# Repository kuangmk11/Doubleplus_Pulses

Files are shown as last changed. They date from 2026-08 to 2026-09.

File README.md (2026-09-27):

# Pulses Plus

A performance-oriented gate router for the Music Thing Turing Machine. Eight pulse channels,
each switchable to one of two merge buses or off; each bus computes the OR or the AND of
whatever is routed to it, chosen live from the panel.

<p align="center">
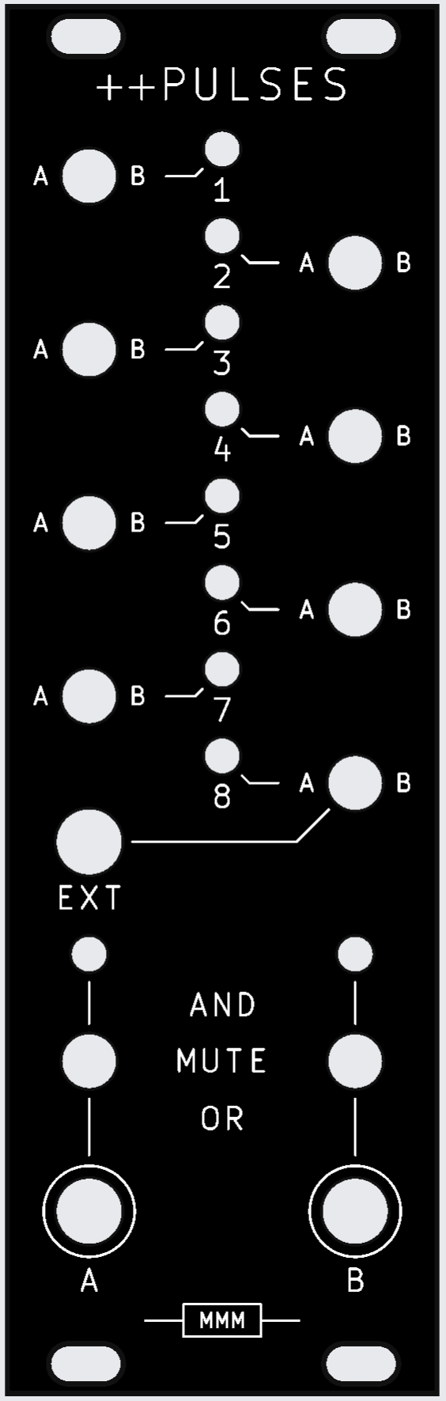
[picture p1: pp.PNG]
Pulses Plus front panel, v4
  
</p>

**Built and tested.** 8 HP, 128.5 × 40.16 mm.

It sits **alongside** a stock Pulses expander rather than replacing it, taking its signals from
the Turing Machine's 16-pin expander ribbon and passing that ribbon through so other expanders
can still be chained downstream.

The stock Pulses gives you seven fixed outputs plus four hard-wired AND combinations. Those AND
outputs are the musical ones — ANDing two shift-register taps gives a sparser, related rhythm.
This generalises that: any subset of the eight bits, OR'd or AND'd, chosen by hand, live. The
four fixed ANDs become a strict subset of what the switches can do.

---

## What's here

| | |
|---|---|
| `pulses_plus_submin.kicad_sch` | schematic — 87 placed components |
| `pulses_plus_submin.kicad_pcb` | main board |
| **`pulses_plus_submin_panel_v4.kicad_pcb`** | **current panel** |
| `pulses_plus_submin_panel.kicad_pcb` | v1 panel — the geometry source `build_panel.py` inherits holes from |
| `pulses_plus_submin.pretty/` | project footprints — toggle, jack, LED, panel holes |
| `switch_fix.kicad_sym` | the DPDT symbol with the pin numbering the footprint expects |
| `3d/` | 3D models the footprints reference |
| `BOM.md` | bill of materials, DigiKey and JLCPCB/LCSC columns |
| `BOM_DigiKey.csv` | the same BOM as a DigiKey cart upload |
| `gerbers/` | fab packages — see below |
| `tools/build_panel.py` | regenerates the panel artwork |
| `PANEL_STYLE_v1.12.md` | the panel house style |
| `docs/pulses-plus-design.md` | full design write-up, including the diode-leak analysis and why 6 HP was abandoned |
| `docs/sw-t2-4x-b-a2-ma2-data-sheet.pdf` | Taiway 200-MDP3 toggle datasheet |

### Which gerbers to order

`gerbers/` accumulated every revision that was sent out. The panel to order is
`gerbers/panelv4.rar`. For the board:

- **`gerbers_v2/`** — current plot of `pulses_plus_submin_v2.kicad_pcb`, **including C5/C6**
  (see the erratum below). Not yet fabbed.
- **`gerbers/controlv2.zip`** — what was actually fabbed and built. Boards from this package
  predate C5/C6 and need the two-capacitor rework.

The loose `.gbr`/`.drl` files at the top of `gerbers/` are the most recent plot of the
main board and the v1/v2 panels, kept unzipped for inspection.

---

## Erratum — ghost triggers on edge-sensitive gate inputs

**Any board built without C5/C6 needs a two-capacitor rework.**

**Symptom.** On the step *after* a real trigger — a step where the bus should be silent — a
downstream envelope fires an extra time. The bus LED never visibly flashes, and the same envelope
behaves correctly on the Turing Machine's own pulse output and on a stock Pulses. A **Kassutronics
ASR** is the known case; the affected class is any gate input that triggers on the *rising edge* at
a low threshold (the ASR's fires from ~+1.2 V).

**Cause.** The Turing Machine's expander bits are `stage AND clock`, and the clock's rising edge
opens that AND before the shift register has finished shifting — so the ribbon briefly presents the
previous step's pattern. This module's two cascaded CD40106 Schmitt buffers then regenerate that
soft sub-µs bump into a sharp, near-full-amplitude micro-gate. Full analysis in
[`docs/pulses-plus-design.md`](docs/pulses-plus-design.md#stale-bit-glitch-and-edge-sensitive-gate-inputs).

**Fix.** Tack a **4.7 nF** ceramic on top of **R15**, and another on top of **R16**. Those 1206 pads
are already `BUSA_SEL`→GND and `BUSB_SEL`→GND on the back of the board, so there are no trace cuts,
no lifted pins, and it is fully reversible. Verified on hardware.

- **Do not use a smaller value.** 1 nF was measured insufficient; 2.2 nF computes marginal.
- **Multing the output is not a workaround.** It appears to help and then stops helping — cable
  capacitance is an order of magnitude too small to filter this.
- The fix is in the **v2** project files (`pulses_plus_submin_v2.*`) as C5/C6. The v1 files do not
  have it.

## How it works

Each channel's DPDT ON-OFF-ON toggle throws left to bus A, right to bus B, or centre for off.
Both poles are used: pole 1 carries only the OR diodes, pole 2 only the AND diodes. That
separation is the one non-obvious constraint in the design — sharing a pole leaks current
through the unselected bus and pins its OR net high.

Per bus, a second toggle picks OR, MUTE or AND. Both nets are computed continuously and in
parallel, so the mode switch only selects which one reaches the output buffer and the 32 merge
diodes never switch. Centre-off leaves the buffer input pulled low, which is the mute.

The **EXT** jack is switched (normalled): unplugged, buffered BIT8 feeds channel 8; plugged, an
external gate takes its place through a transistor and Schmitt stage that squares up whatever
amplitude arrives.

Full write-up: **[`docs/pulses-plus-design.md`](docs/pulses-plus-design.md)**.

## Using it

The two buses are **two independent reads of the same shift register**. Whatever either one
plays is built from the same eight bits on the same loop, so they cannot drift apart — but give
them different channels, or put one in AND and the other in OR, and they come out at different
densities. Related, never identical. Most of the musical mileage is in that gap.

### Gates on A, note changes on B

The patch this turned out to be best at, and not one it was designed for:

1. **OUT A → your envelope or VCA gate.** A few channels to bus A in **OR** — a busy,
   rhythmic gate stream.
2. **OUT B → a quantizer's trigger or sample input**, with the Turing Machine's CV output
   feeding that quantizer's CV input. A *different*, smaller set of channels to bus B, in
   **AND** for something sparser again.

The quantizer only samples when bus B fires, so the note is **held** across every gate bus A
produces in between. A melody moves on its own slow rhythm while the gates articulate
underneath — and because both rhythms are subsets of one register, the note changes land on
beats the gate pattern already stresses. It reads as a phrase, not as two voices running at
once.

Being a Turing Machine underneath, the loop-length and randomness controls then act on the
whole thing at once: lock the register for a repeating riff, open it a crack and the melody
mutates while staying in its scale.

**Pulse width passes straight through.** The board is purely combinational: it merges what
arrives on the ribbon and never looks at the clock. It does not need to — the Turing Machine's
expander bus already carries each bit ANDed with the clock, so the bits arrive as *pulses*, and
the diode merge preserves their width. Feed the TM a narrow clock and the outputs are narrow;
feed it a wide one and they are wide, all the way to OUT A and OUT B.

So an AND that is true on three consecutive steps gives three pulses, one per step — each
re-triggering the envelope or re-pinging the quantizer, rather than merging into one long gate.
The note changes on every step the condition holds, which is why choosing a condition that comes
true *rarely* is what makes the melody move slowly.

**Things to reach for:**

- **B in AND with two or three channels** is the sweet spot. AND of several bits comes true
  rarely, which is what you want from a melody that moves every few bars rather than every step.
- **MUTE on B** freezes the pitch without touching the gate pattern — drop the melody in and
  out by hand mid-take. That is what the centre position is for.
- **The EXT jack earns its keep here.** Patch an outside rhythm into channel 8 and AND it into
  bus B, and the note only changes where your own pattern and the Turing Machine agree —
  a melody keyed to something the TM knows nothing about.
- An **AND bus with nothing routed to it sits high**, held there by its 10k pull-up rather than
  driven by any bit, so it never pings anything. Route at least one channel to a bus you want
  triggers from.

## Key parts

10 × Taiway 200-MDP3 sub-miniature DPDT ON-OFF-ON toggles (ø4.95 bushing), 2 × CD4050 buffers,
1 × CD40106 Schmitt, 33 × 1N4148, 10 × 3 mm LEDs, 3 × Thonkiconn jacks — **J3 must be the
switched variant** — and 2 × 2×8 IDC headers for ribbon in and thru. See [`BOM.md`](BOM.md).

---

## Panel

The current panel is **v4**, `pulses_plus_submin_panel_v4.kicad_pcb` — white silkscreen on black
soldermask, drawn to [`PANEL_STYLE_v1.12.md`](PANEL_STYLE_v1.12.md).

It is generated. [`tools/build_panel.py`](tools/build_panel.py) reads the v1 panel and regenerates
only the artwork, inheriting every control-hole position, so the style guide's one non-negotiable
rule — hole positions are inherited, never computed — holds by construction rather than by
inspection:

```sh
python3 tools/build_panel.py
```

Mounting is four 6.4 × 3.2 mm obround slots on Edge.Cuts, horizontal for ±1.6 mm of slide.
`kicad-cli pcb drc` reports zero violations. Zones refill on open — refill before plotting.

Reading the panel: a ring means signal leaves there, so the two output jacks are the only closed
circles. `A`/`B` beside each toggle are throw directions, not names. The mode stack is `AND` up,
`MUTE` centre, `OR` down. Names sit below the thing they name.

---

## Related repositories

- **[Doubleplus_Pulses_VCV](https://github.com/kuangmk11/Doubleplus_Pulses_VCV)** — a VCV Rack 2 port
  of this module. It reconstructs the Turing Machine's shift register locally, so it runs without
  the hardware.
- **[Turing-Pulse-Expander](https://github.com/kuangmk11/Turing-Pulse-Expander)** — the archive:
  Tom Whitwell's original Rev 2 expander, plus the superseded studies this design grew out of.

## Licence

CC BY-NC-SA 4.0 — see [`LICENSE`](LICENSE).

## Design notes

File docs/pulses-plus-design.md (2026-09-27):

# Pulses Plus — circuit design and netlist

> **A note on what this document describes.** The circuit analysis here is current and applies
> directly to the built module. The *build workflow* it references, however — `build_sch.py`,
> `build_board.py`, `patch_footprints.py` and the generated `Hardware/pulses_plus/` files — belongs
> to the earlier full-size design that this sub-miniature version superseded. Those scripts and
> files stayed behind in the
> [archive repository](https://github.com/kuangmk11/Turing-Pulse-Expander), and the links below
> point there. The shipped module is drawn by hand in KiCad, with only the panel artwork generated,
> by [`tools/build_panel.py`](../tools/build_panel.py).

A performance-oriented gate router for the Music Thing Turing Machine. Eight pulse channels, each
switchable to one of two merge buses (or off); each bus computes OR or AND of whatever is routed to
it, selected live from the panel.

It sits **alongside** a stock Pulses expander rather than replacing it, taking its signals from the
Turing Machine's 16-pin expander ribbon and passing that ribbon through so other expanders can still
be chained downstream.

**Target: 8 HP.** (6 HP was pursued for a long time and is dead — see
[Why not 6 HP](#why-not-6-hp).) Panel study: [`Docs/panel/`](https://github.com/kuangmk11/Turing-Pulse-Expander/tree/main/Docs/panel/).

| File | What it is |
|---|---|
| `Hardware/pulses_plus/pulses_plus.kicad_sch` | schematic — generated, complete |
| `Hardware/pulses_plus/pulses_plus.kicad_pcb` | main board — panel-facing parts placed, rest to do |
| `Hardware/pulses_plus/pulses_plus_panel.kicad_pcb` | front panel — holes + silkscreen |
| `Hardware/pulses_plus/pulses_plus.pretty/` | project footprints (toggle, jack, LED) |
| `Docs/panel_geom.py` | **single source of truth for all panel/board geometry** |

---

## Why this exists

The stock Pulses gives you seven fixed pulse outputs plus four hard-wired AND combinations
(1&2, 2&4, 4&7, 1&2&4&7). Those AND outputs are the musical ones — ANDing two shift-register taps
doesn't produce a rare coincidence, it produces a **thinned, loop-locked rhythm**, because the
register stages are one sequence read at eight different delays, not eight independent random bits.
Which pair you pick changes the pattern; that choice is what you want on a switch, not on a
patch cable.

This module generalises that: any subset of the eight bits, OR'd or AND'd, chosen by hand, live.
The four fixed AND outputs on the stock board become a strict subset of what the switches can do,
so no CD4081 is needed here.

---

## Signal chain

```
TM ribbon ──┬─→ [CD4050 buffers] ──→ P1..P7 ──┬─→ channel LED (4k7)
            │                                  │
            │   BIT8 ──→ [buffer] ──→ P8N ──→ [EXT jack normal] ──→ [Q1 + Schmitt] ──→ P8
            │
            └─→ chain-through header (all 16 pins in parallel)

P1..P8 ──→ [DPDT on-off-on] ──┬─ pole 1 (OR)  ──→ diode ──→ BUS_x_OR   (10k pulldown)
                              └─ pole 2 (AND) ←── diode ←── BUS_x_AND  (10k pullup)

BUS_x_OR ──┐
           ├─→ [SPDT mode switch] ──→ [2× CD40106] ──→ 1k ──→ jack + LED
BUS_x_AND ─┘
```

### Input buffering (why it isn't optional)

Each `BITn` line on the ribbon already drives, on the stock Pulses board, a 2k LED string (~5 mA)
plus a 1k series resistor into a jack. Hanging this module's LEDs and diode network on the same
lines in parallel would roughly double that load and sag the logic highs.

So every bit is buffered on entry by a **CD4050** (non-inverting, happy at +12 V). The ribbon sees
one CMOS input per line; all LEDs and diode current are drawn from the buffer outputs. Side benefit:
every channel now presents the same source impedance to the merge network.

### The diode merge network

Gates need *logical* combination, not voltage addition — two resistor-limited CMOS outputs fighting
over a shared node settle at some mid-rail voltage rather than a clean high or low. So each bus is a
diode network:

| Net | Diode orientation | Pull | Result |
|---|---|---|---|
| `BUS_x_OR` | anode at channel, cathode at bus | 10k **down** to GND | high if **any** routed channel is high |
| `BUS_x_AND` | anode at bus, cathode at channel | 10k **up** to +12 V | high only if **every** routed channel is high |

Both nets are computed continuously and in parallel for both buses. The mode switch sits downstream
and simply picks which net feeds the output buffer, so the 32 merge diodes never switch — only the
selection does.

Levels, with 1N4148 (Vf ≈ 0.7 V) into a CD40106 Schmitt (VT+ ≈ 6.8 V, VT- ≈ 4.5 V at 12 V):

- OR bus, routed channel high: 11.5 − 0.7 = **10.8 V** → comfortably HIGH
- AND bus, routed channel low: 0.1 + 0.7 = **0.8 V** → comfortably LOW

Both have over 3 V of margin, so **Schottky diodes buy nothing here** — plain 1N4148 is fine.

### ⚠ Why the switches must be DPDT, not SPDT

This is the one non-obvious constraint in the whole design, and it is easy to get wrong.

The tempting layout is a single-pole on-off-on switch whose two throws each carry a *pair* of
diodes — one into that bus's OR net, one out of its AND net. **This does not work.** When a channel
is routed to Bus A, its Bus B throw is left floating, and that floating node is connected to *both*
of Bus B's diodes. That completes a DC path straight through the merge network:

```
+12V ── 10k pullup ── [BUS_B_AND] ──▶|── (floating throw) ──▶|── [BUS_B_OR] ── 10k pulldown ── GND
```

Both diodes are forward-biased. The result is a permanent 0.53 mA leakage and **Bus B's OR net
sitting at 5.3 V** — right between the Schmitt thresholds, so the bus is not reliably low. Every
unrouted channel does this, and turning the switch to centre-off doesn't help; it makes it worse by
floating *both* throws.

The fix is to **give the OR and AND networks their own pole**:

- **Pole 1** carries only the OR diodes (throw → anode → bus)
- **Pole 2** carries only the AND diodes (bus → anode → cathode → throw)
- Both poles' commons tie to the same channel signal `Pn`

Now an unselected OR-throw touches only a diode *anode* with nothing to source current into it, so
the bus pulldown wins and the net sits at 0 V. An unselected AND-throw touches only a diode
*cathode*, so it charges to `VDD − Vf` and current stops. There is no path from the AND pullup to
the OR pulldown, and both buses stay clean.

**Required part: DPDT (2-pole) ON-OFF-ON toggle.** Same panel footprint, six pins instead of three.

### Channel 8 and the EXT jack

`BIT8` exists on the ribbon — confirmed against `Hardware/pulses_rev2.sch`, where header pin 8
carries `BIT8` and connects to nothing. The stock Pulses simply never jacks it out. Normalling it
into channel 8 is therefore a legitimate move, not a hack.

The EXT jack is a **switched** (normalled) mono jack. Unplugged, its break contact hands the
buffered `P8N` through to channel 8, so channel 8 is a genuine 8th Turing Machine bit doing real
work. Plug something in and the contact opens, handing channel 8 to whatever you patched.

That makes EXT the one input whose amplitude is unknown, and **the merge network only works if every
channel swings near the rails**. A 5 V gate arriving through a diode drop would not reliably register.
So channel 8 gets a conditioning front end:

```
EXT tip ──[10k]──┬── Q1 base (2N3904)          Q1 collector ──[10k pullup to +12V]── CD40106 ──→ P8
                 ├── [22k] ── GND                    (inverts)                       (re-inverts)
                 └── [1N4148 cathode] ── GND   (clamps negative inputs at −0.7 V)
```

Threshold lands around 1.2 V, so anything from a 3.3 V logic pulse to a 12 V CMOS gate reads
correctly; the 10k base resistor limits current for anything larger, and the clamp diode handles
bipolar sources. The Schmitt gate squares the result.

> **This replaces the LM393 comparator** from the earlier design sketch. The LM393 is
> *open-collector* (KiCad's own symbol marks pins 1 and 7 as such), so it needs a pullup nobody had
> budgeted; worse, its input common-mode range tops out at V+ − 2 V = 10 V, so a 12 V CMOS pulse
> driven straight into it is **out of spec** and would need a divider and a reference on top. The
> transistor front end is one part, has no common-mode limit, needs no reference, and costs one
> spare Schmitt gate we already have.

### Output stage

Per bus: mode switch selects the OR or the AND net → two cascaded CD40106 Schmitt inverters
(double inversion = non-inverting buffer, squared edges, restored rail-to-rail swing) → 1k series
resistor → output jack, with an LED off the same node through 4k7.

A 1M pulldown (R15/R16) on each mode-switch common defines the node during the switch's
make-before-break gap.

**The mode switch is the same DPDT ON-OFF-ON part as the routing switches**, which makes the whole
panel one part number and one footprint — and gives the centre position away for free. With the
common floating, R15/R16 hold the Schmitt input low, so the output goes silent:

> **OR / MUTE / AND** — centre-off mutes the bus.

Only pole 1 is used; pole 2 is left unconnected.

**Known quirk:** AND of zero terms is vacuously true. A bus in AND mode with nothing routed to it
sits high (DC). Harmless, but don't be surprised by it — and the mute position is right there.

### Stale-bit glitch and edge-sensitive gate inputs

**C5/C6 — 4.7 nF from each mode-switch common (`BUSA_SEL` / `BUSB_SEL`) to GND, across R15/R16 —
are not decoupling. They are a required glitch filter**, added after a built module was found to
false-trigger a Kassutronics ASR envelope: on the step *after* a real trigger, on a step where the
bus should be silent, the ASR fired an extra attack. The bus LED never visibly flashed, and the same
ASR was clean on the Turing Machine's own pulse output and on a stock Pulses.

**The mechanism is a race inside the Turing Machine, not on this board.** The ribbon bits are
`stage AND clock`. The clock's rising edge both opens that AND and clocks the shift register, so for
the register's propagation time the ribbon briefly presents the **previous step's pattern**. On the
step after a hit, that stale pattern re-satisfies the same bus condition it satisfied the step
before — in OR mode or in AND mode alike.

**What makes it audible *here* is our own output stage.** Everywhere else in a rack that stale-bit
bump stays small and slow-rising, and nothing notices. This board feeds the merge bus into two
cascaded CD40106 Schmitt inverters, which regenerate anything crossing V<sub>T+</sub> ≈ 6.8 V into a
sharp, near-full-swing micro-gate. The ASR's gate input is an op-amp Schmitt that accepts anything
above ~+1.2 V and **differentiates the rising edge** into its trigger pulse — so it is both far more
sensitive than a CMOS input and sensitive to dV/dt rather than level. A sub-µs, ~2 mA flash of LED9
is invisible, which is why the LED gave no clue.

**The filter belongs ahead of the Schmitt, not at the jack.** Upstream, the glitch only has to be
held below 6.8 V; downstream it is already a clean 12 V pulse that would have to be attenuated below
1.2 V against R17's 1k. That was confirmed on the bench: extra patch cables (~100–300 pF, τ ≈
0.1–0.3 µs) did **not** stop it, while rolling the level off through an attenuverter did. `BUSx_SEL`
also sits at ~10k, ten times the jack's impedance, so a small cap does ten times as much work there,
and costs nothing in edge quality because the Schmitt re-squares everything behind it.

Sizing, with the bus *driven* through ~0.7k (CD4050 output plus merge diode) during the glitch:

| C on `BUSx_SEL` | τ | Peak from a ~1 µs glitch | Tail added (10k·C) | Bench result |
|---|---|---|---|---|
| 1 nF | 0.7 µs | ≈9.1 V | 10 µs | **ghost still present** |
| 2.2 nF | 1.5 µs | ≈5.7 V — 1.1 V margin | 22 µs | not tried; too close to call |
| **4.7 nF** | 3.3 µs | **≈3.1 V** | 47 µs | **ghost gone — shipped value** |

1 nF failing and 4.7 nF working brackets the real glitch at roughly **0.5–2 µs**, wider than the
register's propagation delay alone would suggest. **Do not substitute a smaller value.** The cost of
4.7 nF is 47 µs added to the *passive* edge only — the OR-mode fall and the AND-mode rise — which is
three decades under the TM's millisecond pulse widths.

**Optional refinement for a future board, untested:** a series **22k** between each mode-switch
common and its CD40106 input, with **1 nF** to GND at the gate pin. Driven through 22k, τ ≈ 22 µs
applies to *both* edges, so the delay is symmetric and gate width is preserved exactly instead of
losing a one-sided 47 µs — and it rejects more than the fitted cap does. It needs a trace, so it
cannot be reworked onto an existing board; the plain 4.7 nF stays the default until someone runs it
on a bench.

> **The general lesson.** A Schmitt buffer is a glitch *amplifier*: it takes any excursion past its
> threshold, however brief or soft, and hands on a clean full-amplitude edge. Put one at a module's
> output and you become the module that makes an upstream glitch matter. And some gate inputs
> trigger on dV/dt at ~1 V, so "everything else in my rack ignores this" is not evidence that a
> spike is harmless.

**Reworking a board built before C5/C6 existed:** tack a 4.7 nF ceramic directly on top of R15 and
another on top of R16. Those 1206 pads are already `BUSx_SEL`→GND on the back of the board — no
trace cuts, no lifted pins, fully reversible.

---

## Gate and buffer budget

| IC | Used | Spare |
|---|---|---|
| U1 CD4050 | 6 buffers — BIT1..BIT6 | — |
| U2 CD4050 | 2 buffers — BIT7, BIT8 | 4 (tie inputs to GND) |
| U3 CD40106 | 5 gates — 2× Bus A, 2× Bus B, 1× channel 8 | 1 (tie input to GND) |

CLOCK is present on ribbon pins 9/10 and is passed through to the chain header. It is *not* used,
but a spare U2 buffer and the spare U3 gate mean a clock-as-9th-channel feature could be added later
without another IC.

---

## Netlist

Power comes from the ribbon: **+12 V on pins 15/16, GND on 13/14, −12 V on 11/12** (−12 V is
pass-through only; nothing on this board uses it).

### Connectors

| Ref | Part | Pin | Net |
|---|---|---|---|
| J1 | Conn_02x08_Odd_Even (PULSES IN) | 1–8 | BIT1 … BIT8 |
| | | 9, 10 | CLOCK |
| | | 11, 12 | −12V |
| | | 13, 14 | GND |
| | | 15, 16 | +12V |
| J2 | Conn_02x08_Odd_Even (CHAIN THRU) | 1–16 | *identical to J1, wired in parallel* |
| J3 | AudioJack2_SwitchT (EXT) | T | CH8_IN |
| | | TN | P8N |
| | | S | GND |
| J4 | AudioJack2 (OUT A) | T | OUTA_JACK |
| | | S | GND |
| J5 | AudioJack2 (OUT B) | T | OUTB_JACK |
| | | S | GND |

### Input buffers

| Ref | Pin | Net | | Ref | Pin | Net |
|---|---|---|---|---|---|---|
| U1 (4050) | 3 → 2 | BIT1 → P1 | | U2 (4050) | 3 → 2 | BIT7 → P7 |
| | 5 → 4 | BIT2 → P2 | | | 5 → 4 | BIT8 → P8N |
| | 7 → 6 | BIT3 → P3 | | | 7, 9, 11, 14 | GND *(unused inputs)* |
| | 9 → 10 | BIT4 → P4 | | | 6, 10, 12, 15 | *(no connect)* |
| | 11 → 12 | BIT5 → P5 | | | 1 | +12V |
| | 14 → 15 | BIT6 → P6 | | | 8 | GND |
| | 1 | +12V | | | | |
| | 8 | GND | | | | |

### Channel 8 conditioning

| Ref | Value | From | To |
|---|---|---|---|
| R19 | 10k | CH8_IN | Q1.B |
| R20 | 22k | Q1.B | GND |
| D33 | 1N4148 | cathode Q1.B | anode GND |
| Q1 | 2N3904 | E → GND | C → CH8_COL |
| R21 | 10k | CH8_COL | +12V |
| U3 gate F | 40106 | in 13 = CH8_COL | out 12 = **P8** |

### Routing switches (SW1 … SW8 — DPDT ON-OFF-ON)

For channel *n* ∈ 1…8, with `Pn` the buffered channel signal:

| Pin | Net |
|---|---|
| Pole 1 common | Pn |
| Pole 1 throw A | ORA_n |
| Pole 1 throw B | ORB_n |
| Pole 2 common | Pn |
| Pole 2 throw A | ANDA_n |
| Pole 2 throw B | ANDB_n |

### Merge diodes (D1 … D32, 1N4148)

For channel *n*, diodes `D(4n−3)` … `D(4n)`:

| Diode | Anode | Cathode | Net function |
|---|---|---|---|
| D(4n−3) | ORA_n | BUSA_OR | channel *n* → Bus A, OR |
| D(4n−2) | BUSA_AND | ANDA_n | channel *n* → Bus A, AND |
| D(4n−1) | ORB_n | BUSB_OR | channel *n* → Bus B, OR |
| D(4n) | BUSB_AND | ANDB_n | channel *n* → Bus B, AND |

So D1–D4 are channel 1, D5–D8 channel 2, … D29–D32 channel 8.

### Bus pulls, mode switches, output stage

| Ref | Value | From | To |
|---|---|---|---|
| R11 | 10k | BUSA_OR | GND |
| R12 | 10k | BUSA_AND | +12V |
| R13 | 10k | BUSB_OR | GND |
| R14 | 10k | BUSB_AND | +12V |
| SW9 | DPDT ON-OFF-ON | 1 = BUSA_SEL | 2 = BUSA_OR, 3 = BUSA_AND (pole 2: 4/5/6 n/c) |
| SW10 | DPDT ON-OFF-ON | 1 = BUSB_SEL | 2 = BUSB_OR, 3 = BUSB_AND (pole 2: 4/5/6 n/c) |
| R15 | 1M | BUSA_SEL | GND |
| R16 | 1M | BUSB_SEL | GND |
| U3 gate A | 40106 | in 1 = BUSA_SEL | out 2 = BUSA_N |
| U3 gate B | 40106 | in 3 = BUSA_N | out 4 = **BUSA_OUT** |
| U3 gate C | 40106 | in 5 = BUSB_SEL | out 6 = BUSB_N |
| U3 gate D | 40106 | in 9 = BUSB_N | out 8 = **BUSB_OUT** |
| U3 gate E | 40106 | in 11 = GND | out 10 = *(spare, no connect)* |
| U3 | — | 7 = GND | 14 = +12V |
| R17 | 1k | BUSA_OUT | OUTA_JACK |
| R18 | 1k | BUSB_OUT | OUTB_JACK |

### LEDs

| Ref | Anode from | Resistor | To |
|---|---|---|---|
| LED1 … LED8 | P1 … P8 | R1 … R8, 4k7 | GND |
| LED9 | BUSA_OUT | R9, 4k7 | GND |
| LED10 | BUSB_OUT | R10, 4k7 | GND |

Channel LEDs tap **pre-switch**, so each always shows that channel firing regardless of routing.
4k7 (≈ 2 mA) rather than the stock board's 2k, because a CD4050 output has limited drive at 12 V and
is also feeding the merge diodes — use modern high-brightness LEDs.

### Decoupling

| Ref | Value | Across |
|---|---|---|
| C1, C2, C3 | 100n | U1, U2, U3 VDD → GND |
| C4 | 10µ | +12V → GND (bulk) |

---

## Bill of materials

| Qty | Part | Ref | Notes |
|---|---|---|---|
| 2 | CD4050 hex non-inverting buffer | U1, U2 | input buffering, 8 of 12 used |
| 1 | CD40106 hex Schmitt inverter | U3 | output buffers + ch8, 5 of 6 used |
| 1 | 2N3904 NPN | Q1 | EXT input conditioning |
| 33 | 1N4148 | D1–D33 | 32 merge + 1 EXT clamp |
| 10 | **Adam Tech SW-T2-4X-E-A2-MA2** | SW1–SW10 | DPDT **ON-OFF-ON**, PCB vertical. ⚠ 2-pole is an electrical requirement — see topology note. SW9/SW10 use pole 1 only. |
| 10 | 3 mm LED | LED1–LED10 | high-brightness |
| 2 | 16-pin 2×8 IDC header | J1, J2 | in + chain-through |
| 1 | Switched mono 3.5 mm jack | J3 | EXT — **must** have break contact |
| 2 | Mono 3.5 mm jack | J4, J5 | OUT A / OUT B |
| 10 | 4k7 | R1–R10 | LED |
| 4 | 10k | R11–R14 | bus pulls |
| 2 | 1M | R15, R16 | mode-switch common pulldowns |
| 2 | 1k | R17, R18 | output series |
| 2 | 10k | R19, R21 | EXT base + collector |
| 1 | 22k | R20 | EXT threshold |
| 3 | 100n | C1–C3 | decoupling |
| 1 | 10µ | C4 | bulk |

Estimated current draw from the ribbon's +12 V: ~30 mA (10 LEDs at ~2 mA, four bus pull resistors at
~1.2 mA, ICs a few mA).

## KiCad symbols (verified against KiCad 10 libraries)

| Part | `lib_id` |
|---|---|
| Hex buffer | `4xxx:4050` |
| Hex Schmitt inverter | `4xxx:40106` |
| NPN | `Transistor_BJT:2N3904` |
| Diode | `Diode:1N4148` |
| Routing + mode switch | `Switch:SW_DPDT_x2` |
| Ribbon headers | `Connector_Generic:Conn_02x08_Odd_Even` |
| EXT jack | `Connector_Audio:AudioJack2_SwitchT` |
| Output jacks | `Connector_Audio:AudioJack2` |

Pin numbering used above is taken from these symbols. `SW_DPDT_x2` numbers pole 1 as A=1, B=2, C=3
and pole 2 as A=4, B=5, C=6, with A the common pole.

The schematic is generated by [`build_sch.py`](https://github.com/kuangmk11/Turing-Pulse-Expander/blob/main/Docs/build_sch.py) (with [`ksym.py`](https://github.com/kuangmk11/Turing-Pulse-Expander/blob/main/Docs/ksym.py)), which reads
the symbol definitions straight out of the KiCad libraries so pin numbers and geometry can't drift
from the netlist above. Re-run it to regenerate `Hardware/pulses_plus/pulses_plus.kicad_sch`.
Connectivity is made with net labels on pin stubs rather than routed wires — electrically complete,
but the layout wants tidying by hand.

---

## Mechanical notes (Adam Tech SW-T2-4X-E)

Datasheet: [`sw-t2-4x-b-a2-ma2-data-sheet.pdf`](sw-t2-4x-b-a2-ma2-data-sheet.pdf) (the `-B-` sheet
documents the ON-ON variant; `-E-` is the ON-OFF-ON member of the same family — identical body,
bushing and footprint).

| | |
|---|---|
| Bushing | M6 × 0.75 → **ø6.00 mm panel hole** |
| Body | 13.2 mm along the throw axis × 11.7 mm × 10.6 mm deep |
| Pins | 2 rows × 3, **4.70 mm** within a row, **4.80 mm** between rows; 0.80 × 1.20 mm |
| Mounting | PCB vertical — board sits parallel to the front panel |
| Life | 10 000 cycles (rated at 3 A; effectively far more at signal level) |

**Do not drill the anti-rotation key hole.** Adam Tech's recommended cut-out adds a ø2.40 mm hole
6.40 mm from the bushing centre. Our channel LED sits 7.66 mm from the switch centre with a 1.5 mm
radius, so that key hole's outer edge (7.60 mm) would **overlap the LED hole** (inner edge 6.16 mm)
by about 1.4 mm — one hole drilled into the other. It isn't needed: the six solder pins hold the
switch against rotation once it's PCB-mounted. Panel gets the ø6.00 mm hole only.

Rotated 90° for horizontal throw, the 13.2 mm body against the 6 HP column pitch of 14.5 mm leaves
**1.3 mm between adjacent switch bodies** behind the panel. Same-column switches are 17.25 mm apart
against an 11.7 mm body — 5.5 mm clear.

---

## The panel PCB

> ⚠ **The panel boards are hand-maintained from here on. Do not re-run `build_panel.py` over them.**
> It was scaffolding to get the hole pattern placed, and it has done that job. The committed
> `.kicad_pcb` files are now the source of truth — they carry hand corrections to the mounting holes
> and the silkscreen that the generator does not know about and will overwrite without warning.
> If the hole *pattern* ever needs to change, port the change into the board by hand, or fix the
> generator first and re-apply the hand edits deliberately.

Originally generated by [`build_panel.py`](https://github.com/kuangmk11/Turing-Pulse-Expander/blob/main/Docs/build_panel.py) →
`Hardware/pulses_plus/pulses_plus_panel_6hp.kicad_pcb` (an 8 HP version sits alongside it).

The panel carries **no components**. The switches and jacks are PCB-mounted on the main board behind
it; their bushings pass through and their own nuts hold the panel on. Artwork is on **F.SilkS**, and
the F side faces the player — no mirroring.

| Hole | ø | Count |
|---|---|---|
| Toggle bushing (M6 × 0.75) | 6.00 mm | 10 |
| Jack (Thonkiconn / PJ301M-12) | 6.00 mm | 3 |
| LED (3 mm, with fit clearance) | 3.20 mm | 10 |
| Panel screw (M3) | 3.20 mm | 4 |

**Toggle columns are pinned to the panel edge, not to the centreline** — the nut sits 3.2 mm clear of
the edge — so extra HP goes into the toggle-to-LED gap, which is the only place it's needed.

Clearances at 8 HP (40.16 × 128.5 mm):

- tightest hole-to-hole: **4.80 mm** — comfortable for any fab
- tightest hole-to-edge: 1.40 mm (at the M3 holes)
- centreline LED to toggle **body**: **3.40 mm** (this was −0.90 mm at 6 HP)

**The mounting holes as generated are not to spec** — ø3.2 mm round holes, 7.5 mm in from each side
edge, 3.0 mm from top and bottom — and do not match the Eurorack rail pattern. Fix by hand on the
board; treat the board, not the script, as correct.

---

## Why not 6 HP

Worth recording, because the panel *holes* fit at 6 HP and everything looked fine right up until it
wasn't.

The toggle's **bushing** is 6 mm, but its **body** is 13.7 mm across (courtyard). At 6 HP the two
toggle columns sit 14.4 mm apart on centre, which leaves **1.2 mm between the two bodies** — and the
LED spine runs down the middle of exactly that gap. A 3 mm LED does not fit in a 1.2 mm slot:

```
6 HP panel                            30.0 mm
  left toggle body    1.2 .. 14.4
  right toggle body  15.6 .. 28.8      -> 1.2 mm between them
  LED (3 mm) at 15.0 needs            13.5 .. 16.5
  => LED body overlaps BOTH toggles by ~0.9 mm
```

A centreline LED needs `2 × (7.8 + 6.85) + 3.9 + clearance ≈ 33.3 mm`, so 6 HP misses by over 3 mm.
No LED size rescues it — even a 2 mm LED still needs more than 30 mm. Only a narrower-bodied
sub-miniature DPDT would have, and at $3.99 each plus 30 % tariff that was worse than spending 2 HP.

**The lesson, and the reason `panel_geom.py` exists:** a PCB DRC checks copper and holes. It does not
check the *bodies* of through-panel hardware, and on this module the bodies are what decide the
width. All geometry is now solved from real footprint extents with an explicit body-clearance check,
so this class of mistake fails loudly instead of silently.

> Two things a PCB DRC will *not* catch, because neither is a board feature: the switch **nut**, a
> washer sitting on top of the panel, and the switch **body** behind it. Both are checked by
> `build_panel.py` and in the mechanical notes above.

---

## The main board

`Hardware/pulses_plus/pulses_plus.kicad_pcb`, generated by [`build_board.py`](https://github.com/kuangmk11/Turing-Pulse-Expander/blob/main/Docs/build_board.py).

The board sits **behind** the panel with its F side facing the player, so panel (x, y) and board
(x, y) are the **same frame — no mirroring**. Only the parts that must line up with panel holes are
placed: 10 toggles, 3 jacks, 10 LEDs. ICs, passives and the ribbon headers are left for hand
placement.

Board outline is 39.16 × **110 mm**, centred on the panel, which is what clears the Eurorack rails
top and bottom. Every body clearance is ≥ 1.00 mm and nothing sits outside the outline;
`build_board.py` refuses to write the file if any two bodies overlap.

No 6 mm hole in the *board* for the toggles: these are the PCB-vertical variant, so the body sits on
the PCB and only the bushing passes through the panel.

Footprint fields on all 90 schematic symbols are filled in by
[`patch_footprints.py`](https://github.com/kuangmk11/Turing-Pulse-Expander/blob/main/Docs/patch_footprints.py) — an in-place patch, so it won't clobber hand edits to
the schematic. Panel-facing parts use the project library; the rest are stock KiCad SMD parts chosen
to match the Rev 2 board's style. Change them freely.

> ⚠ **Verify the toggle pad mapping with a meter before ordering boards.** The datasheet does not
> number the terminals. `SW_T2_4X_DPDT` assumes the **centre pin of each row of three is the common**
> (rows = poles), and that pad 2 is the **right-hand** pin because a toggle connects its common to
> the terminal *opposite* the way the lever is pushed (lever left → right-hand terminal → Bus A).
> The common-in-centre assumption is the critical one. If the lever sense is inverted, Bus A and
> Bus B simply swap — cosmetic, fixable by relabelling.

---

## Open questions

1. **Toggle pad mapping** — verify with a meter (above). This is the only thing that could scrap a
   board run.
2. **Mounting holes** — not to spec, fix by hand on the panel.
3. FR4 panels with zero copper: some fabs want a minimum copper area. Add a token pour if yours
   complains.
4. Whether to expose CLOCK as a ninth channel later, using the spare U2 buffer and U3 gate.

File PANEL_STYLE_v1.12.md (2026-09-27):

# Front panel style

**Version 1.12.**

House style for my module front panels — what marks go on them, what each one means, and
where it sits. It is a drawing spec, not a program: a panel is in the style if it satisfies
the rules below, whether it was generated or drawn by hand.

The look is borrowed from RYO's *Altered States* (`reference.jpg`) and is deliberately
PCB-native: single-weight plotter lettering, connections routed the way a trace is routed,
and dots where a silkscreen would have vias. Printed as white silkscreen on black
soldermask.

The rules were fitted to a set of eleven generated Kassutronics panels. That is where the
numbers come from, and why some are stated to the hundredth of a millimetre — they were
measured off production artwork, not chosen.

## Two ways to draw one

**Generated.** One `<stem>.layout.json` per panel says what its controls are and how they
relate; every mark comes from a single style library, so changing a number there changes
every panel at once.

```sh
tools/build_styled_panels.sh            # every finished layout
tools/build_styled_panels.sh Slope      # just the ones whose path matches
```

Outputs land beside each source as `<stem>.styled.{panel.json,kicad_pcb,svg}`, leaving the
PDF-derived conversions untouched.

**Drawn.** A hand-written SVG at 1:1, one user unit = 1 mm — `docs/v3-panel.svg` in this
repo is one. Nothing below needs a generator; the tokens are just numbers.

Where a rule is easier to state as tool behaviour ("the composer refuses to write if…"), it
is stated here as the rule being enforced. A generator should enforce it. A hand drawing has
to be checked.

## The one rule that is not negotiable

**Control hole positions are inherited, never computed.**

A panel serving a board that already exists — a port of someone else's module, or a revision
like this adder's v3 — takes its hole positions from that board and may not move them. A
panel whose holes move stops fitting its main board. v3 reassigns hole *diameters* between
6 mm jack and 5 mm toggle and keeps all sixteen positions from the built v2.2 panel.

On a genuinely new board the positions are fitted once, when the board is laid out, and are
inherited from then on.

Either way, **every hole is accounted for**, so a jack cannot silently vanish because a
layout forgot it.

Mounting holes are the exception: they meet the rails, not the module's own board, so they
are regenerated (below).

## Tokens

Every value is one number in one place. A generator holds them together; a hand drawing
copies them from here.

| | value | |
|---|---|---|
| `LINE_W` / `RULE_W` | 0.25 / 0.20 mm | wires, brackets, rings / centre divider |
| `LABEL_SIZE` | 2.0 mm | control labels |
| `SMALL_SIZE` | 1.6 mm | crowded rows, notes, bracket labels |
| `TITLE_SIZE` | 3.2 mm | module name |
| `LOGO_SIZE` | 1.3 mm | wordmark |
| `TRACK_LOGO` / `TRACK_TIGHT` | 0.34 / 0.22 mm | tracking at `LOGO_SIZE`; 0.26 / 0.17 of cap |
| `TRACK_MONO` | 0.06 mm | the `MMM` monogram, set tight |
| `TRAVEL_DOT_D` / `TRAVEL_END_D` | 0.9 / 1.4 mm | knob travel marks |
| `DOT_D` | 0.6 mm | star-field, when used at all |
| `RING_R` / `RING_W` | 4.75 / 0.5 mm | the output ring: fixed radius, drawn heavier than `LINE_W` |
| `LABEL_GAP` | 1.2 mm | drawn extent → nearest edge of the label cell |
| `LABEL_GAP_HW` | 2.2 mm | the same gap at a jack or a switch, where a nut takes the extra |
| `EDGE_MARGIN` | 0.6 mm | no silkscreen closer than this to the cut |
| `DASH_LEN` / `DASH_GAP` | 0.8 / 0.6 mm | a normal: the only dashed line on a panel |

**The face is Routed Gothic.** Every letter, on the panel and off it — silkscreen, the
wordmark, web artwork, banners, favicons. It is the technical-drawing lettering the style
was always reaching for: uniform stroke, rounded terminals, no optical corrections, and
correct by construction rather than by eye.

Use the **stroke source**, not the compiled font: `src/basefont/routed-gothic-stroke-source.sfd`
in [dse/routed-gothic](https://github.com/dse/routed-gothic) holds skeletons before the
stroke is expanded, so a glyph is a centreline that can be drawn at `LINE_W` like any other
mark. Its cap height spans 656 units on the baseline at y = 40; scale that to `LOGO_SIZE`
(or `LABEL_SIZE`, or whatever the row calls for) and the letters land at the house weight.
One wrinkle: the source contours are thin closed racetracks about 0.032 mm across, so
stroke at `LINE_W − 0.032` to finish at a true 0.25.

Routed Gothic is **SIL Open Font License 1.1** — free for commercial use, which is the
reason it is the house face and not Gorton. GortonDigital is the closer revival of the
original engraving type, but it is licensed for non-commercial use only and so cannot go on
anything the shop sells. Where a shape is in doubt, Gorton is a legitimate reference to
*look* at; only Routed Gothic outlines get shipped.

**Tracking.** The reference's lettering is monospaced and widely tracked, but Routed Gothic
is proportional, and fixed pitch strands its narrow glyphs: `I` is 0.032 mm of ink, which
floats in the middle of a 1.45 mm cell with 1.418 mm of air either side against the `M`'s
0.340 mm. So text is still set **one character at a time** — KiCad has no letter-spacing
setting, and the generator places each character anyway — but each advances by **its own
width plus a fixed tracking**, not by a shared pitch. Everything is uppercase.

| | value | |
|---|---|---|
| `TRACK_LOGO` | 0.34 mm | the wordmark, widely tracked as the reference is |
| `TRACK_TIGHT` | 0.22 mm | panel labels, and the wordmark where the width is short |
| `TRACK_MONO` | 0.06 mm | the `MMM` short form |

`TRACK_MONO` is tighter than either because the short form is a **monogram, not a word**:
three identical letters that should read as one mark. Tracked at `TRACK_LOGO` they drift
apart and start reading as an abbreviation being spelled out. Judge it at the size the mark is actually reproduced — the site header renders it 44 px
tall — not at the size you draw it. At 0.06 the diagonals close right up without touching;
by about 0.04 they start to merge.

Both are ratios of cap height — 0.26 and 0.17 — so a label at `LABEL_SIZE` tracks 0.52 /
0.34 mm and a title at `TITLE_SIZE` tracks 0.83 / 0.54 mm. At `LOGO_SIZE` they come out at
the two values above. `TRACK_TIGHT` on the full wordmark returns it to 28.85 mm, within a
rounding error of the 29.0 mm the old fixed pitch produced, which is what makes it the
drop-in choice when a panel is short of room.

The `PITCH_*` tokens are retired. They described a monospaced setting the house face does
not have.

## Marks and what they mean

**Knob travel — a dotted arc.** Eleven dots every 30°, at every position except +90°; the
gap at the bottom is where the label goes and the two dots either side of it, at +120° and
+60°, are the ends of travel and are drawn heavier. These positions are not invented: they
are measured off the starbursts on the ASR, both Attenumix panels and the Avalanche VCO,
which all draw the same 300° pot. The radius sits inside the band that artwork occupies —
3.75 to 8.06 mm on a 7.5 mm pot — so the marks stay visible with a knob fitted.

```
        ·  ·  ·               11 dots, r = hole_r + 3.45
      ·         ·
    ·     (O)     ·           hole
      ·         ·
     ●           ●            heavy: ends of travel, +120 / +60
          FOLD                the 30 deg gap at +90
```

- a **small** knob pulls the radius in for tightly spaced rows (Slope's Shape/Sustain sit on
  13.3 mm centres);
- a **big** knob draws **two** concentric rings, for an oversized main knob whose starburst
  runs out to 18.5 mm rather than 8.5 — the 3340 and KS-20 Frequency, the Ladder Filter, the
  Wavefolder's Fold;
- **bipolar** adds a heavier dot at 12 o'clock for the centre detent, and sets `-` / `+`
  outside the travel ends;
- **named ends** do the same with words, for the KS-20's `LP` / `HP` Mode.

**A ring means signal leaves here.** Every jack is an input or an output, and an output
draws the ring. Keeping it the only closed circle on a panel is what lets direction read at
a glance — which is also why nothing else may be a closed circle.

The ring is **`RING_R` = 4.75 mm radius at `RING_W` = 0.5 mm**, both absolute: the radius is
not measured out from the hole edge, and the line is twice the panel weight. A 6 mm jack
leaves 1.75 mm of bare panel between hole and ring, which is the gap a fitted nut needs
before the circle starts reading as part of the hardware. Drawn at `LINE_W` it disappeared
next to the type around it; at `RING_W` it is the heaviest mark on the panel, which is the
right ranking for the one thing that states direction. The retired `RING_GAP` token
described the old hole-relative construction and is gone — a ring is a fixed circle now, the
same size on every panel whatever the jack.

**A bracket groups one direction only.** It says *these belong together*, so enclosing an
input and an output in one misstates the signal flow. A bracket that mixes directions is an
error, not a judgement call. Labels sit in gaps in the bracket's own top edge. An output row
inside a bracket does not also get rings — the bracket already says it.

**An outline groups by function, not direction.** A plain rounded box at the lighter rule
weight, drawn round everything belonging to one section — the Quantizer's two channels, each
of which necessarily has both an input and an output, so the bracket's one-direction rule
does not apply. Where a bracket labels a row in its own top edge and must not mix
directions, an outline just says *this lot is one thing*.

**A span is one shared label** over a bar covering the controls it names, with a tick turning
down at each end — the 3340's two V/Oct inputs get one word, not the same word twice.

**A wire is a connection**, routed with one knee using only 0°, 90° and 45° segments,
stopping short of what it joins and breaking around any label it passes under. Routing does
**not** avoid obstacles: check that a wire does not cross a control, or drop it.

**A dashed line is a normal** — a connection that holds until a cable goes in, and breaks
when one does. Every normalled input is called out, because it is the one behaviour a
player cannot see: an unpatched input that is quietly receiving a signal. A solid wire says
*always connected*; a dash says *connected until you patch here*, which is exactly what a
switched jack does. It is drawn at `LINE_W` in `DASH_LEN` dashes separated by `DASH_GAP`,
starting and ending on a dash, and nothing else on a panel may be dashed.

- **Normalled from another jack** — channel 2's input taking channel 1's signal. The dash
  runs from the source jack to the normalled one, routed and stopped short exactly like a
  wire. Direction needs no arrow: the source is an output or an input further up the chain,
  and the ring already says which.
- **Normalled to a fixed voltage or an internal signal** — the Attenuverter's inputs, each
  normalled to +5 V so that with nothing patched its knob becomes an offset. There is no
  source jack to run to, so the value is set as text at `SMALL_SIZE` on the side of the jack
  **opposite its name**, `LABEL_GAP_HW` clear of the nut, with a single `DASH_LEN` dash
  between the value and the jack's drawn extent. The dash is what separates it from a name:
  `+5V` on its own above a jack reads as that jack being called `+5V`.

Write the value as the circuit supplies it, **with its sign**: `+5V`, `-10V`, not `5V` — on a
±12 V system the sign is part of the value. An internal signal takes its short name, `LFO`,
`NOISE`. Mark every normalled input where it sits, even when a whole column shares one
value: the four Attenuverter channels each carry `+5V`, for the same reason every ++PULSES
toggle carries its own throw marks — the answer belongs at the jack the hand is on.

Normals to ground are **not** marked. An input switched to 0 V when unpatched behaves as if
nothing is there, which is what an unmarked input already says.

## Layout

**A name goes below the thing it names.** Every jack, every LED, every pot, every switch —
one rule, no exceptions, measured from whatever is drawn around the hole (a pot's travel
ring, an output's ring) and not from the hole itself. A panel where some names sit above
and some below makes the reader work out which each time.

**Text clears a jack or a switch by `LABEL_GAP_HW`, everything else by `LABEL_GAP`.** The
gap runs from the drawn extent to the nearest edge of the label cell, and it applies to a
name below a control and to a position mark beside one alike. Jacks and switches get the
extra millimetre because neither is flush with the panel: a nut, and on a toggle its
shoulder, stand proud of the artwork and swallow the clearance a drawing says is there.
Measured on `++PULSES`, the `A` / `B` throw marks at 1.2 mm sat against the toggle nuts and
the `EXT` name tucked under the jack nut — all three arithmetically clear, all three wrong
in the hand. LEDs, pots and buttons keep `LABEL_GAP`: a travel ring is already drawn out
past anything a knob covers, and an LED has no nut.

**A mark that means a position goes where that position is.** Travel dots ring the pot,
`+` and `−` straddle a toggle, selector values stack beside the throws they select. These
are not names and the rule above does not apply to them — a `+` under a switch is wrong
however consistent it looks.

That leaves the case where a switch needs a name *and* position marks. The name takes the
baseline of the topmost position mark, off to one side of it. It must not sit directly
outboard of a `+` on the same baseline, or the two read as one word — `+OCTAVE`.

Three things adjust themselves and should not be fought:

- a row whose labels would collide, or would need shoving back inside the board, drops to the
  small size **as a whole row**;
- every label in a row is snapped to one baseline, so a ringed output does not sit 1.2 mm
  below its plain neighbours;
- the title shrinks to fit the clear span between the mounting slots.

When a row still needs help, in the order to reach for it: the small size, a larger label
gap, the label moved to a named direction, the label placed at an explicit `[x, y]`. An
explicit title height and size exist for panels where a control near the top leaves only
~2 mm of clear band.

## Mounting

Regenerated to one rule, as 6.4 × 3.2 mm obround slots milled on Edge.Cuts — horizontal, so
a module can slide ±1.6 mm to meet its neighbours.

| | |
|---|---|
| vertical | centre 3.0 mm from the top and bottom edges |
| horizontal | centre 7.5 mm in from the edge; the opposite column steps out by N × 5.08 mm |
| **> 6 HP** | both columns, 4 slots — 8 HP at 7.5 / 32.9, 10 HP at 7.5 / 43.06 |
| **≤ 6 HP** | one slot top and bottom on **opposite corners**, top right and bottom left. One screw per rail is enough at that width, and diagonal placement stops the module pivoting. |

The 7.5 mm inset is the datum and the grid steps out from it, so the far margin lands at
7.26–7.44 rather than exactly 7.5. That is the way round that matters: the grid is what the
rail is drilled to.

Where the panel is inherited (above), its existing mounting holes win — a v2.2-era panel with
round Ø3.2 holes keeps them.

## The wordmark

**The mark names who designed the module.**

| the design is | the panel says |
|---|---|
| mine, original | `MISSING MILE MODULAR` — `MMM` where the width does not allow it |
| a port or revision of someone else's | that maker's name — `KASSUTRONICS`, `KT` on 4 HP |
| this precision adder | `508`, which is what the built v2.2 panel carries, kept for continuity |

Whatever the word, it is letterspaced inside a plain two-lead component frame — the same
schematic-fragment idea as RYO's, a different part. It sits at `height − 7.0`, above the
mounting line, because a 6.4 mm slot leaves only 17.8 mm between the bottom pair and a full
wordmark needs 19.0. At 4 HP the bottom margin has only ~7 mm of clear width, which is what
the short forms are for.

## The back of the panel

The front says who designed the module in three letters. The back says it in full, and
says what may be done with the design — it is the one surface with room, and nothing on
it competes with the artwork.

Two things go there, both on `B.SilkS`, uppercase and letterspaced like everything else,
at `SMALL_SIZE` or just under:

| | |
|---|---|
| credit | `DESIGNED BY MISSING MILE MODULAR <year>` — the year the artwork was cut, not the year the circuit was designed |
| licence | the short form **with its version**, e.g. `CC BY-NC-SA 4.0`. No URL: it will not be read off the back of a module, and it costs a line |

The licence is stated exactly, clause letters and all. `CC-BY-SA` and `CC BY-NC-SA 4.0`
are different licences — one permits commercial builds of the module, the other does not —
and the back of the panel is where that is on the record. Carry the version number too: the
CC licences are not identical across versions, and a bare family name dates badly.

Wrap the credit rather than shrink it. Below about 1.2 mm the strokes start to fill in on
black soldermask, so a long name becomes two lines at the small size, never one line at a
size chosen to fit.

**Placement is whatever the holes leave.** Control holes go clean through, so the back has
no artwork of its own to work around and no keepouts but the holes themselves. Find the
clear bands between hole rows and set the type in those; a band needs the line height plus
`EDGE_MARGIN` top and bottom. There is no fixed position, because no two panels leave the
same gaps.

**Back text is emitted right-to-left.** KiCad mirrors each glyph about its own anchor, so
a run of cells laid out left-to-right in board coordinates reads backwards once the board
is turned over. Since the tracking rule already sets every character in its own cell, the
fix is to reverse the cell order — the string is unchanged, the cells are dealt out from
the right. A generator does this; a hand drawing has to be checked against a mirrored
render, not against the editor.

## Screw holes

3.4 mm holes fix the board behind the panel. They are drilled and then ignored: they need no
layout entry, take no label and get no marks. Mounting slots are treated the same way.

## Copper

**Both copper layers are poured solid, edge to edge.** One filled zone on `F.Cu` and one on
`B.Cu`, each drawn past the board outline so KiCad clips it to `Edge.Cuts` — the pour
follows the cut and any change to the outline, with no polygon to keep in step by hand.

| | value | |
|---|---|---|
| net | `GND` | named, even when nothing on the panel connects to it |
| fill | solid | not hatched |
| clearance | 0.5 mm | to holes, slots and anything else the pour meets |
| min thickness | 0.25 mm | = `LINE_W` |
| island removal | always | a floating sliver is fab dirt in copper |
| priority | `B.Cu` 1, `F.Cu` 0 | only matters if the two ever overlap on one layer |

The reason is how the panel looks and handles, not electrical. Black soldermask over copper
reads as an even, slightly raised gloss; over bare FR-4 it goes flat and patchy, and a
panel with copper in some places and not others shows the seams. A full pour on both sides
also keeps the two faces balanced so a thin panel stays flat, and stiffens it under a
tightened jack nut.

The pour is **covered by soldermask everywhere**. Nothing opens it: silkscreen sits on mask
over copper exactly as it would on mask over laminate, and no mark on the panel is ever
drawn in exposed copper. Holes and slots clear the pour by the 0.5 mm clearance, so a
plated barrel or a nut never touches copper through the mask.

For a hand drawing there is nothing to draw — the pour is a board-house setting, and it
goes in when the SVG becomes a board. For a generated panel, the composer writes both zones.
Either way, **refill before DRC** (`B` in the editor, or `kicad-cli pcb drc --refill-zones`)
so the check sees the copper that will actually be made.

## The star-field

Off. The reference's scatter reads as texture because it covers a whole panel edge to edge;
here, once the keepouts around holes, wires, brackets and type have taken their share, there
is nothing left but orphans — measured, 15 of 17 survivors on Slope had no near neighbour,
and the ASR had none at all. An orphan dot reads as fab dirt. The travel rings already carry
the polar-dot language.

It stays available, and a panel that turns out to have real open space can opt back in.

## Per-module cases

Rules that exist for one panel and are recorded so they are not mistaken for house style.

**The Kassutronics Quantizer's glyphs.** Its shift layer is iconographic, and those icons are
what its user manual teaches, so they are redrawn rather than replaced with words — twelve of
them, each built in a local box running -1..1 from the same strokes and arcs as everything
else and scaled on placement:

| button | glyph | function |
|---|---|---|
| 0 | `gate_length` | gate length — a crotchet and a minim, a short note and a long one |
| 1 | `rotate` | rotate menu |
| 2 / 3 | `transpose_both` / `transpose_one` | transpose |
| 4 / 5 | `offset_both` / `offset_one` | offset |
| 6 | `keyboard` | keyboard mode |
| 7 | `legato` | legato — two crotchets under a slur |
| 8 | `gear` | settings |
| 9 | `tau` | gate length |
| 10 / 11 | `cv_a` / `cv_b` | CV A / CV B menus |

The "both channels" glyphs carry two marks where the "one channel" ones carry one — the
distinction the original draws, and the one the manual describes. `tau` is drawn rather than
set, so it cannot depend on the stroke font carrying Greek.

**The keyboard ring inverts.** The original fills the five *black* keys as wedges on a white
panel. Straight onto black soldermask that reading breaks, so the seven **white** keys are
filled instead and the black keys are left as bare panel — same keyboard, same contrast,
opposite ink. Adjacent white keys (E–F, B–C) merge into one shape, as on a real keyboard.
Each wedge subtracts its own scale button's hole with clearance rather than printing over it.
The numbers moved outside the keyboard ring to make room, and **3 and 9 are omitted** — they
sit dead on the panel edges, exactly as on the original.

**Pulses Plus, and what an 8 HP panel of nothing but toggles forces.**

*The title wraps.* `DOUBLEPLUS++PULSES` is eighteen characters, which at `TITLE_SIZE`
wants around 60 mm on a 40 mm panel (61 mm measured under the retired fixed pitch; the
proportional setting is within a millimetre or two of it at this length). Shrinking it to fit puts the title at label size, where it
stops reading as a title at all. It breaks to two lines at the full `TITLE_SIZE` instead,
centred in the band between the top mounting holes and the first LED. Prefer two full-size
lines to one shrunken one whenever the clear band is tall enough.

*The bus indicator LEDs take no label.* Each bus is a column — indicator, mode switch,
output jack, in line — and the jack at the foot of the column is labelled `A` or `B`. A
letter on the LED as well would print the same word twice in 25 mm. This is a real
exception to "every LED gets a name", allowed only because the column reads as one thing
and the name is directly below it.

*`AND` / `MUTE` / `OR` is one stack between two switches.* Both mode switches carry the
same three positions, and the centre position cannot be marked where it is — that is the
hole. So the three words sit in the centre column, on the switches' own baselines, serving
both. Position marks normally go beside the control they belong to; here they go between
two identical controls, which is the only reading that does not double them.

*The throw marks do not.* All eight routing toggles throw on the X axis and are wired
identically, so `A`/`B` could have been said once. It is said on every switch, because it
is a position mark and not a name: the panel has to answer "which way is bus A" at the
switch the hand is on, not at the top of the column.

**LPG-MIX MK3, and adding controls to a panel that is already drawn.**

*The panel's own metric wins over this document.* MK3's panel was drawn before v1.08 retired
the fixed pitch: every label on it is 1.6 mm on a 1.70 mm pitch, one character per cell. The two
controls MK3 adds are set the same way. A label in the current proportional metric would be
correct by this spec and visibly wrong beside `MODE`. Where a panel already exists, match it, and
note the exception here rather than half-converting the artwork.

*`SW7` gets no name.* It carries three position marks — `33N` above, the unmarked centre, `110N`
below, on `SW5`'s own two mark baselines — and no name of its own. There is nowhere to put one:
`RANGE` at `SMALL_SIZE` needs about 9 mm and the only gap is the 5.2 mm between `SW5`'s `LPG` mark
and `SW7`'s hole. The three capacitance values are self-describing, and the switch is paired
vertically with its marks while the neighbouring `MODE` reads horizontally, so the two switches
do not get confused.

*`DECAY` and `SW7` get no outline.* They are one function and the outline rule would fit, but any
box wide enough to hold both also swallows the variation row's `3` mark, which belongs to a
different group. A grouping mark that has to enclose a foreign label is worse than no grouping
mark.

*Clearance on an inherited panel is checked relatively, not absolutely.* Nominal hardware radii
say the built panel collides with itself everywhere — knobs overlap, travel dots sit under the
knob, labels tuck under nuts — because the artwork is drawn tighter than nominal and works. So
the check measures what the existing panel already demonstrates for each hole diameter, and
requires new controls to be no tighter than that. Absolute thresholds only produce noise.

*Render it.* MK3's `SW7` passed every numeric clearance check at its first position and was still
wrong: the hole sat on top of an existing label the arithmetic had not been told about. Rule 4
below is not optional.

## Checking a panel

For a generated panel, start from a stub with every hole classified by diameter and each
label `TODO`; the build skips any layout still containing `TODO`.

```sh
python3 tools/panel_compose.py --stub documentation/Foo/Foo.panel.json
```

Then, in this order, however the panel was made:

1. **every control matched and every hole accounted for** — no unmatched control, no
   unaccounted hole;
2. **hole positions identical to the board's.** Compare against the drill file, not against
   the last drawing;
3. **no collisions.** For a KiCad panel, `kicad-cli pcb drc` reports **zero** violations —
   not "warnings only", since the keepouts are under our control and anything surviving is
   real. For a drawn panel, print at 100%, check the sheet measures what the drawing claims,
   and check clearance on anything unproven by an existing build;
4. **rasterise it and look at it.**

## Versioning

**Any change to this document increments the version by one hundredth** — v1.02 → v1.03 →
v1.04, and so on. There is no distinction between a typo and a new rule; every edit is a
bump.

Two things move together, and a change that touches only one of them is incomplete:

1. the version line at the top of this file;
2. the filename — `PANEL_STYLE_v1.04.md` → `PANEL_STYLE_v1.05.md`. Rename with `git mv` so
   the history follows the file.

Then update anything pointing at the old filename (`README.md`).

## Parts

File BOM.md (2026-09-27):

# Pulses Plus (sub-mini) — Bill of Materials

Generated from `pulses_plus_submin_v2.kicad_sch` (89 placed components, 19 line items).
Two sourcing columns:

- **DigiKey** — for hand assembly (the THT parts and jacks are hand-solder anyway).
- **JLCPCB / LCSC** — the LCSC `C`-number is what JLCPCB SMT assembly needs for the SMD parts.

Switches are sourced from **Love My Switches** (they are the Taiway 200 sub-mini toggles,
not a DigiKey/LCSC stock part).

> ⚠ **Verify before ordering** — part numbers marked *(verify)* are the correct manufacturer
> series but the exact distributor SKU / LCSC stock C-number should be confirmed against live
> stock at order time. Confirmed numbers came from distributor listings and are noted as such.

---

## BOM table

| # | Qty | Value | Refs | Package / Footprint | Mfr Part | DigiKey | JLCPCB / LCSC |
|---|-----|---|---|---|---|---|---|
| 1 | 10 | **DPDT ON-OFF-ON toggle** | SW1–SW10 | Taiway 200 sub-mini, PC vertical, ø4.95 bushing | Taiway **200-MDP3-T2B1M2QE** | — | — |
| 2 | 2 | CD4050 hex buffer | U1, U2 | DIP-16 | **CD4050BE** (TI) | 296-2056-ND | C(verify) |
| 3 | 1 | CD40106 hex Schmitt | U3 | DIP-14 | **CD40106BE** (TI) | 296-9797-5-ND *(verify)* | **C71251** |
| 4 | 1 | MMBT3904 NPN | Q1 | SOT-23 | **MMBT3904** | MMBT3904FSCT-ND | **C20526** |
| 5 | 33 | 1N4148 switching diode | D1–D33 | SOD-123 (`Diode_SMD:D_SOD-123`) | **1N4148W** | 1N4148W-FDICT-ND | **C81598** |
| 6 | 10 | 4k7 resistor | R1–R10 | 1206, 1% | Yageo **RC1206FR-074K7L** | search mfr PN | C(verify) |
| 7 | 6 | 10k resistor | R11–R14, R19, R21 | 1206, 1% | Yageo **RC1206FR-0710KL** | search mfr PN | C(verify) |
| 8 | 2 | 1k resistor | R17, R18 | 1206, 1% | Yageo **RC1206FR-071KL** | search mfr PN | C(verify) |
| 9 | 1 | 22k resistor | R20 | 1206, 1% | Yageo **RC1206FR-0722KL** | search mfr PN | C(verify) |
| 10 | 2 | 1M resistor | R15, R16 | 1206, 1% | Yageo **RC1206FR-071ML** | search mfr PN | C(verify) |
| 11 | 3 | 100n capacitor | C1, C2, C3 | 1206, X7R, 50V | Samsung **CL31B104KBCNNNC** | 1276-1092-1-ND *(verify)* | C(verify) |
| 12 | 1 | 10µ capacitor | C4 | 1206, X5R, 25V | Samsung **CL31A106KBHNNNE** | 1276-1940-1-ND *(verify)* | C(verify) |
| 13 | 10 | 3mm LED, high-brightness | LED1–LED10 | 3mm THT | e.g. Kingbright WP710A10 series | any 3mm LED | — |
| 14 | 3 | 3.5mm mono jack "Thonkiconn" | J3 (EXT, switched), J4 (OUT A), J5 (OUT B) | PJ301M-12 / PJ398SM | **PJ398SM** | not stocked | not stocked |
| 15 | 2 | 2×8 IDC box header, 2.54mm | J1 (PULSES IN), J2 (CHAIN THRU) | shrouded, vertical | generic 2x8 IDC | 2×8 shrouded header | C(verify) |
| 16 | 2 | **4.7n capacitor** | C5, C6 | 1206, X7R, 50V | Samsung **CL31B472KBCNNNC** *(verify)* | search mfr PN | C(verify) |

**C5/C6 are the glitch filter** — 4.7 nF from each mode-switch common (`BUSA_SEL` / `BUSB_SEL`)
to GND, sitting across R15/R16. They are not decoupling and not optional: without them the module
passes a sub-µs stale-bit spike from the Turing Machine's expander bus through its Schmitt output
buffers, which false-triggers edge-sensitive gate inputs (a Kassutronics ASR is the known case).
**Do not substitute 1 n or 2.2 n** — 1 n was measured insufficient and 2.2 n computes marginal. See
the design doc's *Stale-bit glitch* section.

**J3 must be the switched (normalling) variant** — its break contact normals buffered BIT8 into
channel 8. J4/J5 are plain mono. All three are the same Thonkiconn body.

---

## Sourcing notes

**Switches (SW1–SW10) — Love My Switches**
Taiway **200-MDP3-T2B1M2QE**, "Sub-Mini DPDT On-Off-On, PCB Mount, Short Shaft."
~$2.15 ea (≈ $21.50 for 10). Body 8.1 × 23.2 mm, ships with two nuts + a washer.
Product page: <https://lovemyswitches.com/taiway-sub-mini-dpdt-on-off-on-switch-pcb-mount-short-shaft/>
Panel hole is ø4.95 mm (10-48 UNS bushing). All 10 switches are this one part.

**Thonkiconn jacks (J3/J4/J5)** — not a DigiKey/LCSC catalog part. Buy from Thonk, Love My
Switches, Synthrotek, or Oddvolt (PJ398SM / PJ301M-12; the two are interchangeable). If you want
JLCPCB to place them, you'll need to supply them as a consigned part or substitute a catalog jack
with the same footprint.

**Resistors** — Yageo RC1206 series part numbers above are deterministic (`RC1206FR-07` + value
code + `L`, F = 1%). Any 1206 thick-film at 1% is fine; values are non-critical. On JLCPCB these
are Basic parts — pick the in-stock C-number for each value in the parts tool.

**Ceramics** — 100n/10µ 1206 X7R/X5R; any reputable 1206 MLCC works. The Samsung CL31 series
numbers are representative JLCPCB Basic parts.

---

## Action items before fab

1. **Diode footprint — RESOLVED in the v2 project.** All 33 diodes (D1–D33) are on
   `Diode_SMD:D_SOD-123`, part **1N4148W / C81598 / DK 1N4148W-FDICT-ND**, in *both*
   `pulses_plus_submin_v2.kicad_sch` and `pulses_plus_submin_v2.kicad_pcb` — verified by inspection,
   so *Update PCB from Schematic* no longer reverts them to 1206. Nets intact (8 diodes per bus,
   pad 1 = K → bus/GND, pad 2 = A).
   > ⚠ The **v1** files (`pulses_plus_submin.kicad_sch`) still carry the old 1206 footprint fields.
   > Work in the v2 project.

2. **Meter the switch** — confirm centre pin = common on the actual Taiway part before committing
   to a board run (design open-question #1). Everything assumes centre-is-common.

3. **LED polarity/brightness** — footprint pad 1 = cathode → GND, pad 2 = anode → 4k7. Use
   modern high-brightness 3mm LEDs (drive is only ~2 mA through 4k7 from a CD4050 output at 12 V).

---

## Verified vs. representative

| Confirmed from distributor listings | Representative (confirm at order) |
|---|---|
| Taiway 200-MDP3-T2B1M2QE (Love My Switches) | CD4050BE LCSC C-number |
| CD4050BE — DigiKey 296-2056-ND | CD40106BE DigiKey SKU |
| CD40106BE — LCSC C71251 | all passive LCSC C-numbers |
| MMBT3904 — LCSC C20526 | ceramic cap DigiKey SKUs |
| 1N4148W — LCSC C81598, DigiKey 1N4148W-FDICT-ND | LED / IDC header specifics |

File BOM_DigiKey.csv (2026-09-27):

Quantity | Part Number | Customer Reference | Description
33 | 1N4148W-7-F | D 1N4148W | DIODE STANDARD 100V 300MA SOD-123 SMD
10 | RC1206FR-074K7L | R 4k7 | RES 4.7K OHM 1% 1/4W 1206 SMD
6 | RC1206FR-0710KL | R 10k | RES 10K OHM 1% 1/4W 1206 SMD
2 | RC1206FR-071ML | R 1M | RES 1M OHM 1% 1/4W 1206 SMD
2 | RC1206FR-071KL | R 1k | RES 1K OHM 1% 1/4W 1206 SMD
1 | RC1206FR-0722KL | R 22k | RES 22K OHM 1% 1/4W 1206 SMD
3 | C1206C104K5RACTU | C 100n | CAP CER 0.1UF 50V X7R 1206 SMD
1 | C1206C106K8PACTU | C 10uF | CAP CER 10UF 10V X5R 1206 SMD
10 | WP710A10ID | D LED 3MM | LED RED DIFFUSED 3MM T-1 THROUGH HOLE
2 | CD4050BE | IC CD4050B | IC BUFFER NON-INVERTING HEX 16-DIP
1 | CD40106BE | IC CD40106B | IC INVERTER SCHMITT TRIGGER HEX 14-DIP
1 | MMBT3904LT1G | Q MMBT3904 | TRANS NPN 40V 200MA SOT-23 SMD
2 | SBH11-PBPC-D08-ST-BK | J 2X8 IDC | CONN HEADER SHROUDED 2X8 2.54MM - PULSES IN AND CHAIN THRU
2 | C1206C472K5RACTU | C 4.7nF | CAP CER 4700PF 50V X7R 1206 SMD

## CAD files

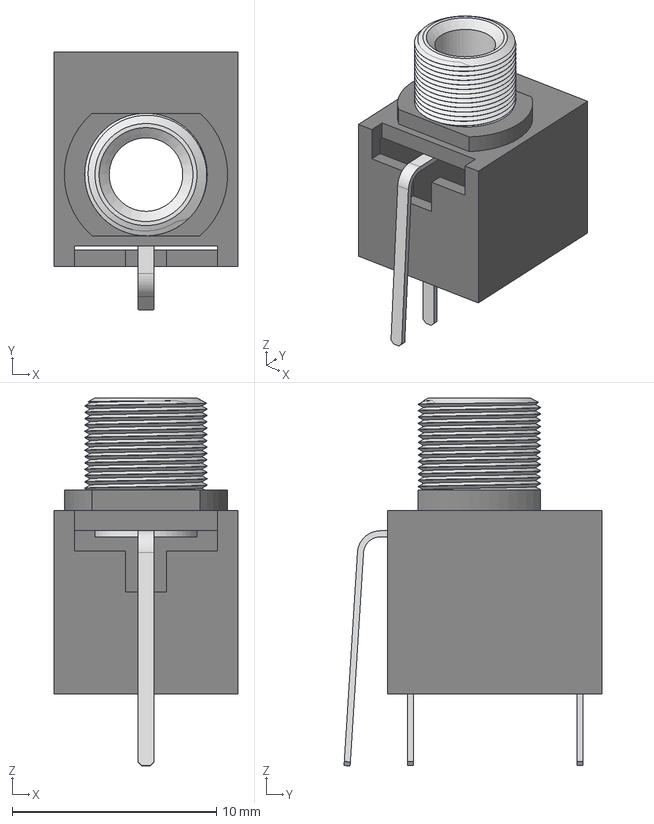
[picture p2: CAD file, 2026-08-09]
3d/PJ301M-12 Thonkiconn v0.2.stp
9.00 x 12.6 x 18.0 mm

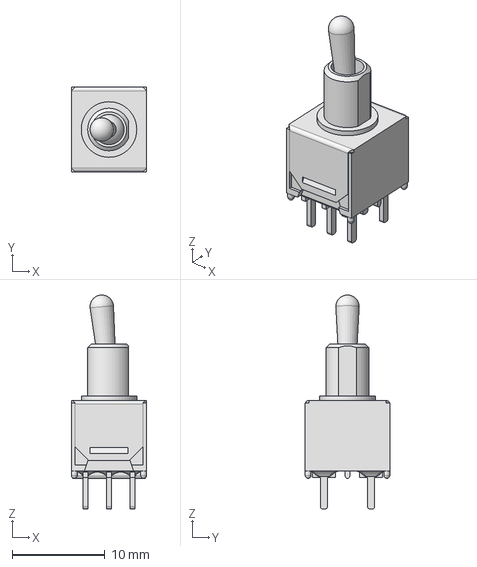
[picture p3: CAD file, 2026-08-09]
3d/200MDPxT2B1M2xE.stp
8.13 x 9.14 x 23.1 mm

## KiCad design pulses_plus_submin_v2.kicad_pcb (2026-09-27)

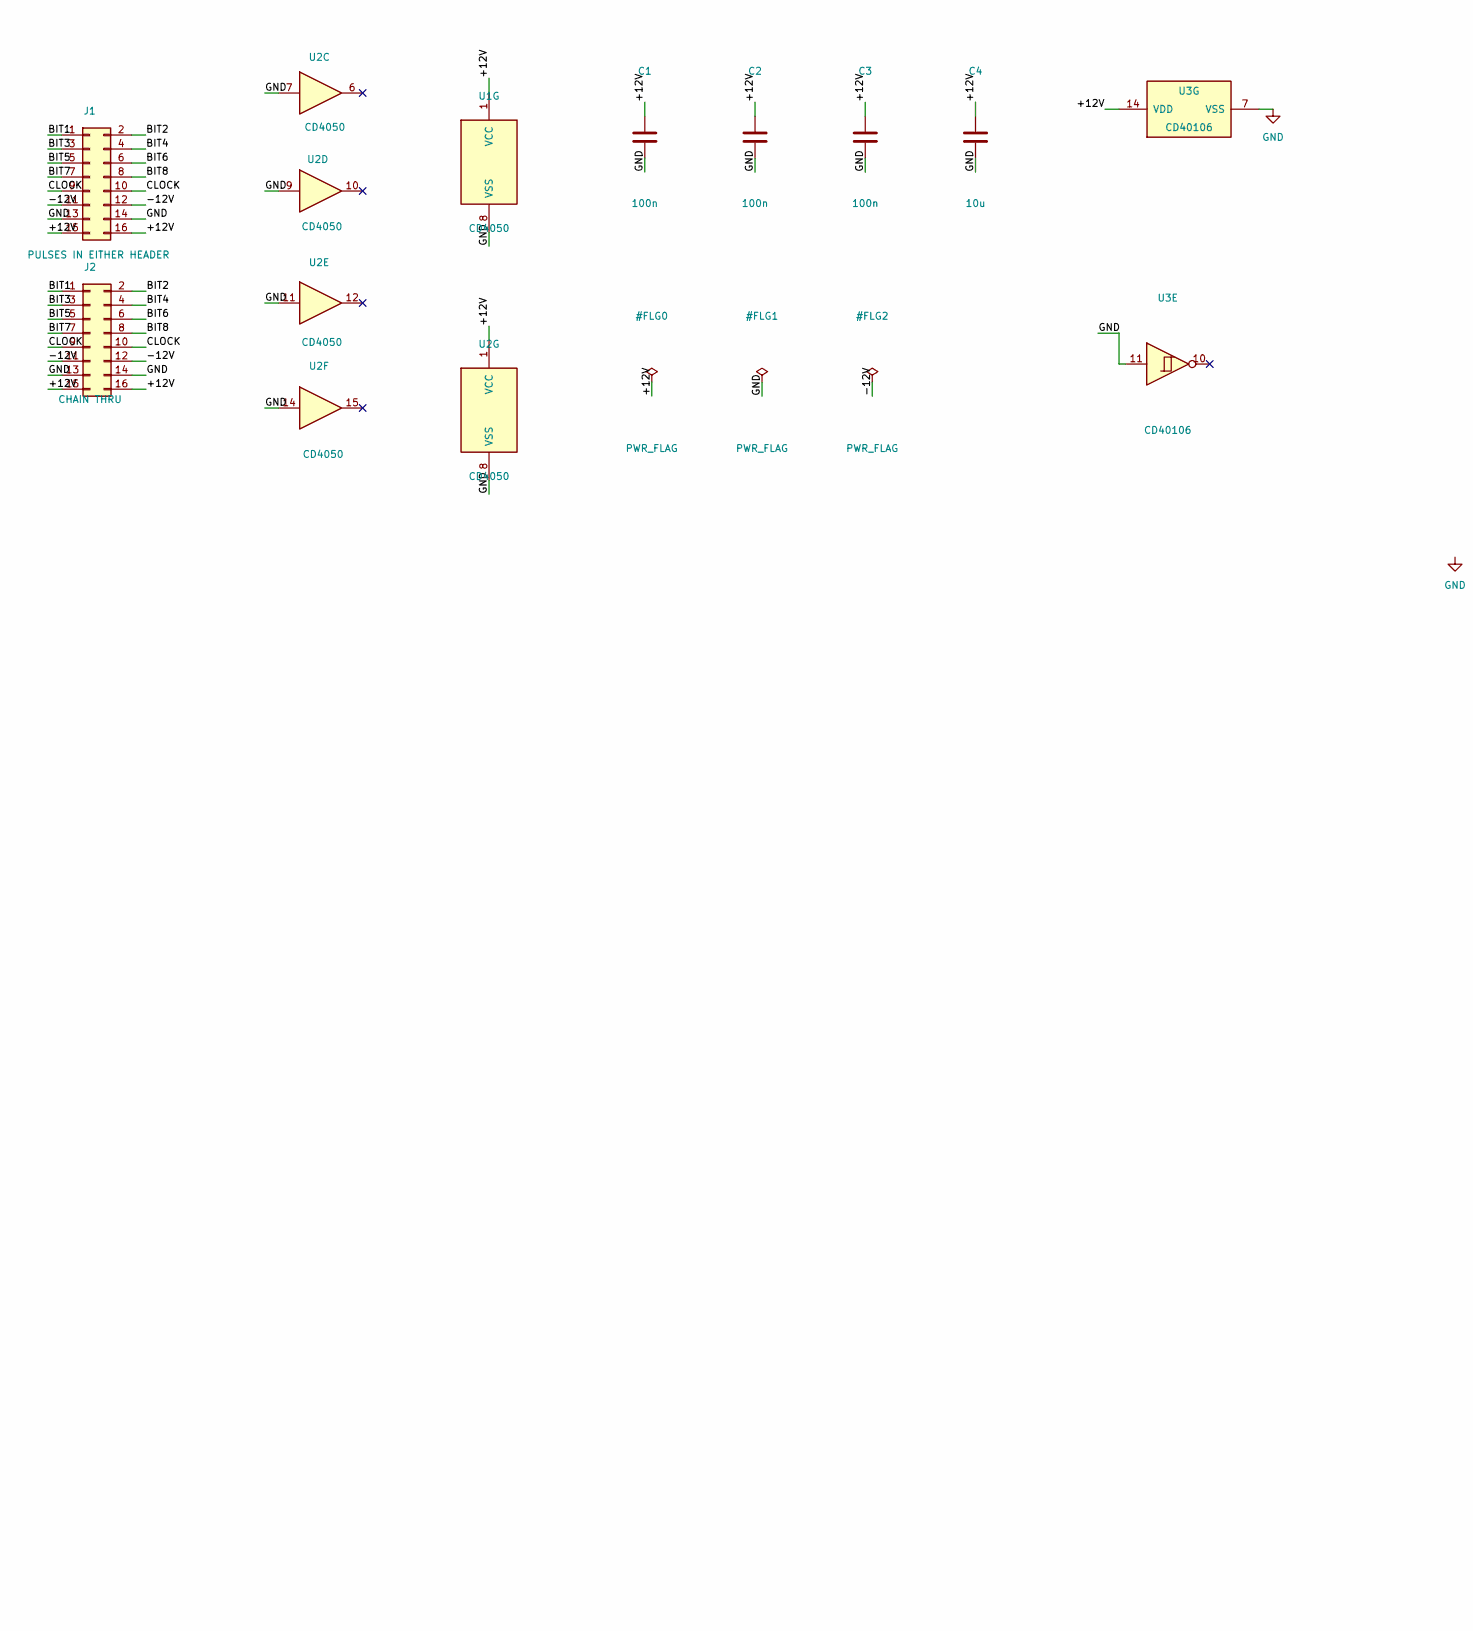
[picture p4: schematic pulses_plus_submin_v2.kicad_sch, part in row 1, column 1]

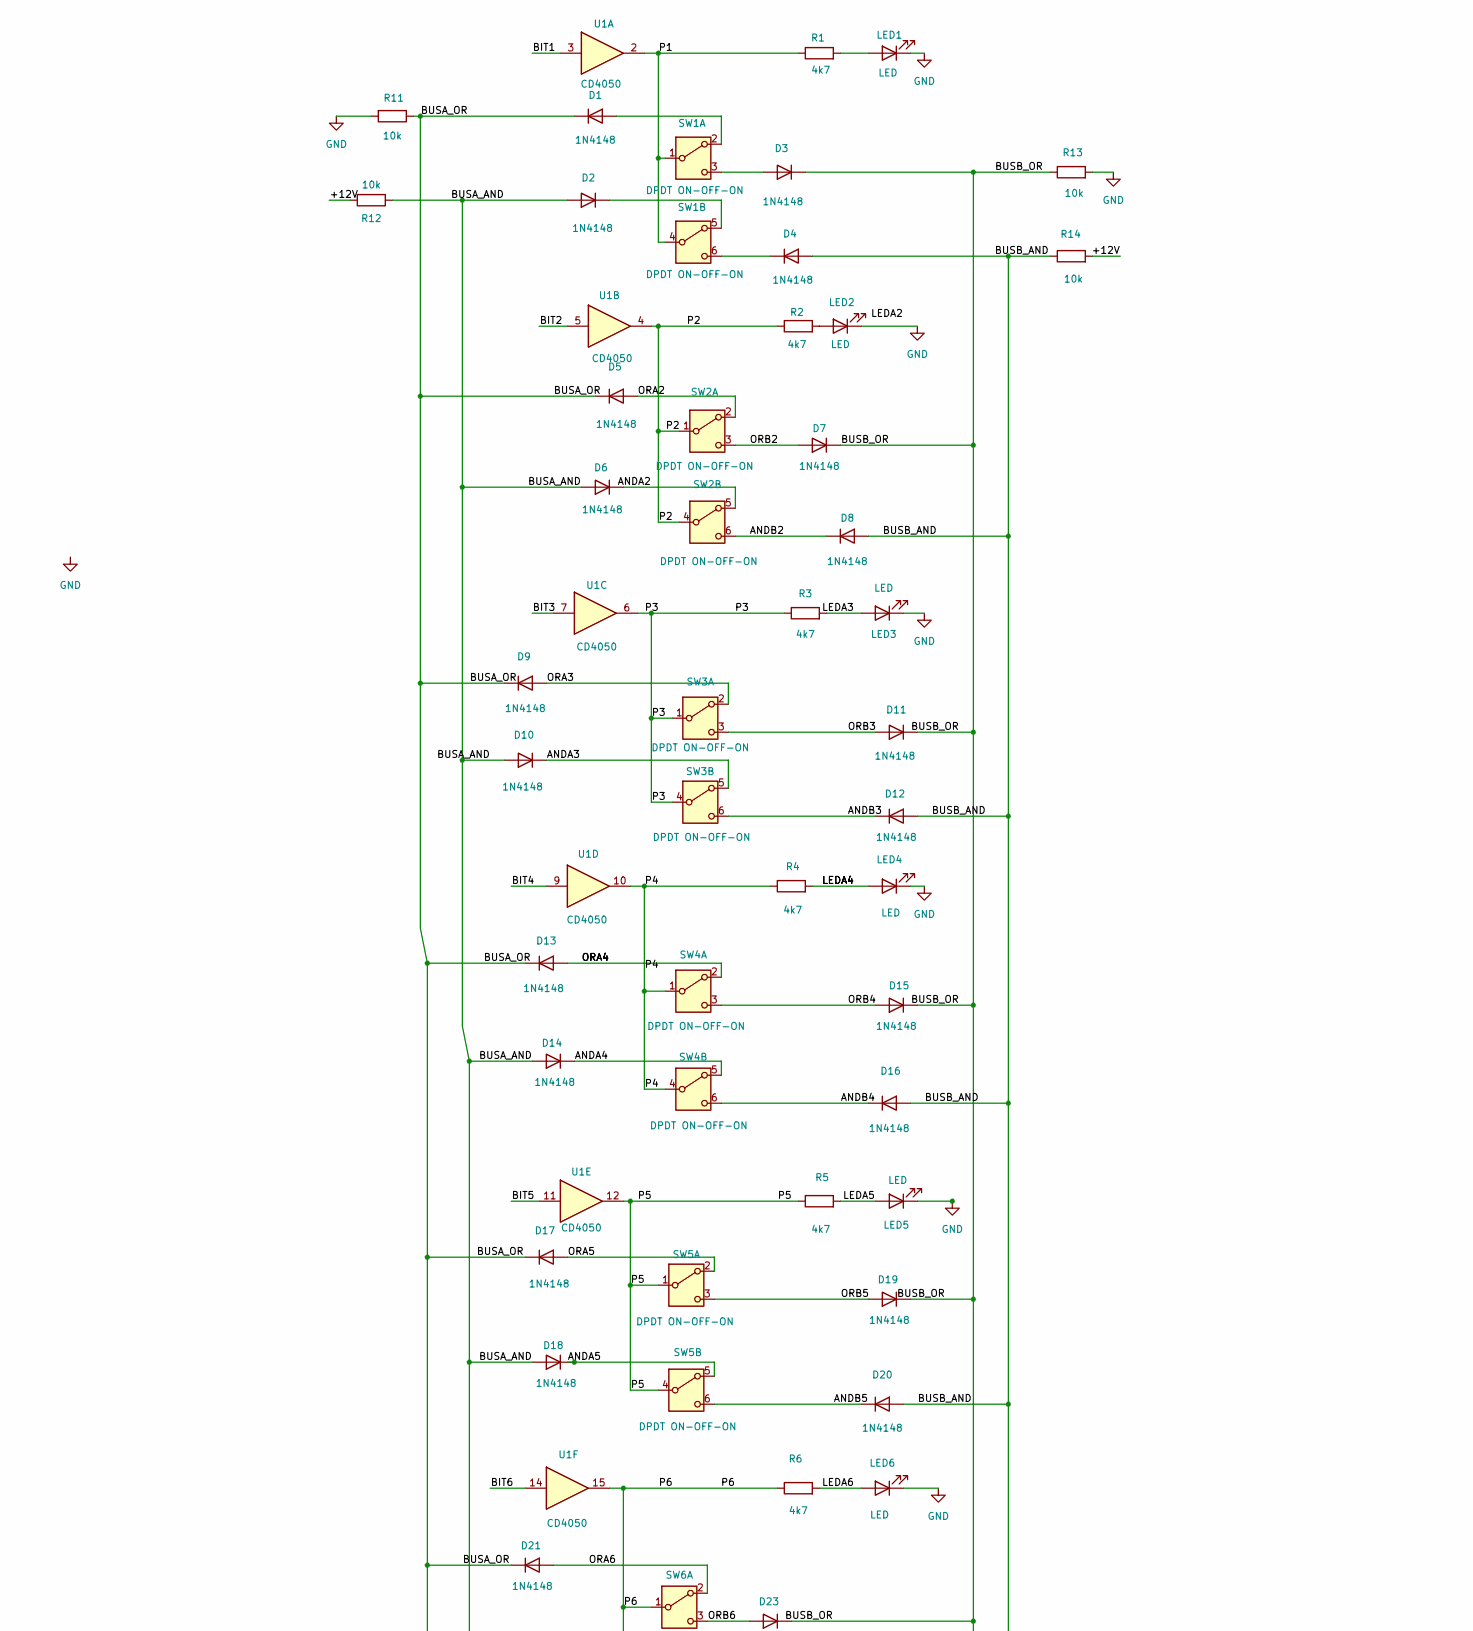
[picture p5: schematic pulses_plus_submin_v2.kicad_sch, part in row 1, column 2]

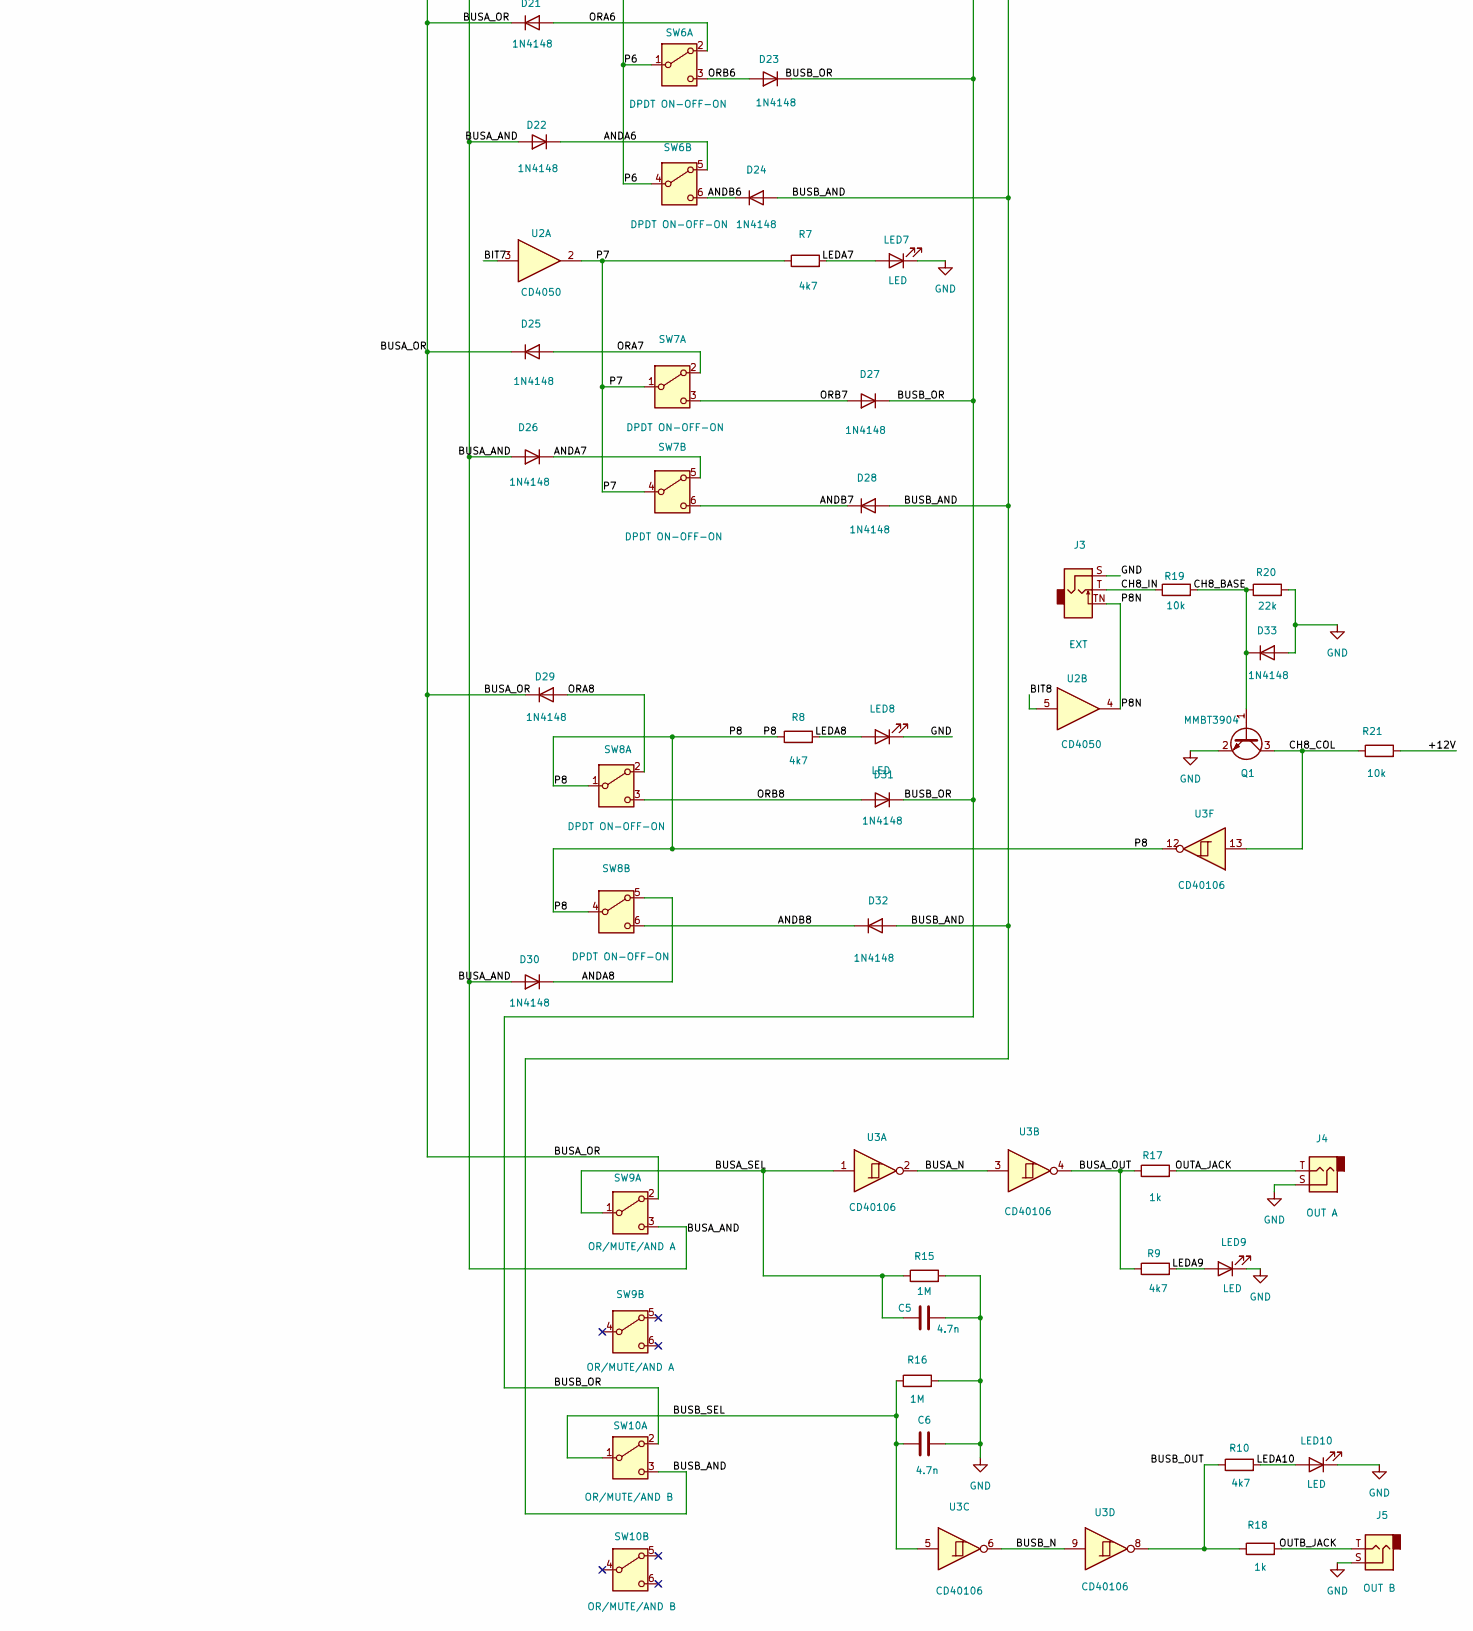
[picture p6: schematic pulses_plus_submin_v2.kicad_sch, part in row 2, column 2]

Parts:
C1, C2, C3: 100n; C_1206_3216Metric_Pad1.33x1.80mm_HandSolder
C4: 10u; C_1206_3216Metric_Pad1.33x1.80mm_HandSolder
C5, C6: 4.7n; C_1206_3216Metric_Pad1.33x1.80mm_HandSolder
D1, D2, D3, D4, D5, D6, D7, D8, D9, D10, D11, D12, D13, D14, D15, D16, D17, D18, D19, D20, D21, D22, D23, D24, D25, D26, D27, D28, D29, D30, D31, D32, D33: 1N4148; D_SOD-123
J1: PULSES IN EITHER HEADER; IDC-Header_2x08_P2.54mm_Vertical
J2: CHAIN THRU; IDC-Header_2x08_P2.54mm_Vertical
J3: EXT; Thonkiconn_PJ301M
J4: OUT A; Thonkiconn_PJ301M
J5: OUT B; Thonkiconn_PJ301M
LED1, LED2, LED3, LED4, LED5, LED6, LED7, LED8, LED9, LED10: LED; LED_D3.0mm
Q1: MMBT3904; SOT-23
R1, R2, R3, R4, R5, R6, R7, R8, R9, R10: 4k7; R_1206_3216Metric_Pad1.30x1.75mm_HandSolder
R11, R12, R13, R14, R19, R21: 10k; R_1206_3216Metric_Pad1.30x1.75mm_HandSolder
R15, R16: 1M; R_1206_3216Metric_Pad1.30x1.75mm_HandSolder
R17, R18: 1k; R_1206_3216Metric_Pad1.30x1.75mm_HandSolder
R20: 22k; R_1206_3216Metric_Pad1.30x1.75mm_HandSolder
SW1, SW2, SW3, SW4, SW5, SW6, SW7, SW8: DPDT ON-OFF-ON; SW_200_MDP3_DPDT
SW9: OR/MUTE/AND A; SW_200_MDP3_DPDT
SW10: OR/MUTE/AND B; SW_200_MDP3_DPDT
U1, U2: CD4050; DIP-16_W7.62mm
U3: CD40106; DIP-14_W7.62mm

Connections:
/+12V: C1.1, C2.1, C3.1, C4.1, J1.15, J1.16, J2.15, J2.16, R12.2, R14.2, R21.2, U1.1 (VCC), U2.1 (VCC), U3.14 (VDD)
/-12V: J1.11, J1.12, J2.11, J2.12
/ANDA2: D6.1 (K), SW2.5 (B)
/ANDA3: D10.1 (K), SW3.5 (B)
/ANDA4: D14.1 (K), SW4.5 (B)
/ANDA5: D18.1 (K), SW5.5 (B)
/ANDA6: D22.1 (K), SW6.5 (B)
/ANDA7: D26.1 (K), SW7.5 (B)
/ANDA8: D30.1 (K), SW8.5 (B)
/ANDB2: D8.1 (K), SW2.6 (C)
/ANDB3: D12.1 (K), SW3.6 (C)
/ANDB4: D16.1 (K), SW4.6 (C)
/ANDB5: D20.1 (K), SW5.6 (C)
/ANDB6: D24.1 (K), SW6.6 (C)
/ANDB7: D28.1 (K), SW7.6 (C)
/ANDB8: D32.1 (K), SW8.6 (C)
/BIT1: J1.1, J2.1, U1.3
/BIT2: J1.2, J2.2, U1.5
/BIT3: J1.3, J2.3, U1.7
/BIT4: J1.4, J2.4, U1.9
/BIT5: J1.5, J2.5, U1.11
/BIT6: J1.6, J2.6, U1.14
/BIT7: J1.7, J2.7, U2.3
/BIT8: J1.8, J2.8, U2.5
/BUSA_AND: D2.2 (A), D6.2 (A), D10.2 (A), D14.2 (A), D18.2 (A), D22.2 (A), D26.2 (A), D30.2 (A), R12.1, SW9.3 (C)
/BUSA_N: U3.2, U3.3
/BUSA_OR: D1.1 (K), D5.1 (K), D9.1 (K), D13.1 (K), D17.1 (K), D21.1 (K), D25.1 (K), D29.1 (K), R11.1, SW9.2 (B)
/BUSA_OUT: R9.1, R17.1, U3.4
/BUSB_AND: D4.2 (A), D8.2 (A), D12.2 (A), D16.2 (A), D20.2 (A), D24.2 (A), D28.2 (A), D32.2 (A), R14.1, SW10.3 (C)
/BUSB_N: U3.6, U3.9
/BUSB_OR: D3.1 (K), D7.1 (K), D11.1 (K), D15.1 (K), D19.1 (K), D23.1 (K), D27.1 (K), D31.1 (K), R13.1, SW10.2 (B)
/BUSB_OUT: R10.1, R18.1, U3.8
/CH8_BASE: D33.1 (K), Q1.1 (B), R19.2, R20.1
/CH8_COL: Q1.3 (C), R21.1, U3.13
/CH8_IN: J3.T, R19.1
/CLOCK: J1.9, J1.10, J2.9, J2.10
/LEDA3: LED3.2 (A), R3.2
/LEDA5: LED5.2 (A), R5.2
/LEDA6: LED6.2 (A), R6.2
/LEDA7: LED7.2 (A), R7.2
/LEDA8: LED8.2 (A), R8.2
/LEDA9: LED9.2 (A), R9.2
/LEDA10: LED10.2 (A), R10.2
/ORA2: D5.2 (A), SW2.2 (B)
/ORA3: D9.2 (A), SW3.2 (B)
/ORA5: D17.2 (A), SW5.2 (B)
/ORA6: D21.2 (A), SW6.2 (B)
/ORA7: D25.2 (A), SW7.2 (B)
/ORA8: D29.2 (A), SW8.2 (B)
/ORB2: D7.2 (A), SW2.3 (C)
/ORB3: D11.2 (A), SW3.3 (C)
/ORB4: D15.2 (A), SW4.3 (C)
/ORB5: D19.2 (A), SW5.3 (C)
/ORB6: D23.2 (A), SW6.3 (C)
/ORB7: D27.2 (A), SW7.3 (C)
/ORB8: D31.2 (A), SW8.3 (C)
/OUTA_JACK: J4.T, R17.2
/OUTB_JACK: J5.T, R18.2
/P1: R1.1, SW1.1 (A), SW1.4 (A), U1.2
/P2: R2.1, SW2.1 (A), SW2.4 (A), U1.4
/P3: R3.1, SW3.1 (A), SW3.4 (A), U1.6
/P4: R4.1, SW4.1 (A), SW4.4 (A), U1.10
/P5: R5.1, SW5.1 (A), SW5.4 (A), U1.12
/P6: R6.1, SW6.1 (A), SW6.4 (A), U1.15
/P7: R7.1, SW7.1 (A), SW7.4 (A), U2.2
/P8: R8.1, SW8.1 (A), SW8.4 (A), U3.12
/P8N: J3.TN, U2.4
GND: C1.2, C2.2, C3.2, C4.2, C5.2, C6.2, D33.2 (A), J1.13, J1.14, J2.13, J2.14, J3.S, J4.S, J5.S, LED1.1 (K), LED2.1 (K), LED3.1 (K), LED4.1 (K), LED5.1 (K), LED6.1 (K), LED7.1 (K), LED8.1 (K), LED9.1 (K), LED10.1 (K), Q1.2 (E), R11.2, R13.2, R15.2, R16.2, R20.2, U1.8 (VSS), U2.7, U2.8 (VSS), U2.9, U2.11, U2.14, U3.7 (VSS), U3.11
unnamed: D1.2 (A), SW1.2 (B)
unnamed: D2.1 (K), SW1.5 (B)
unnamed: D3.2 (A), SW1.3 (C)
unnamed: D4.1 (K), SW1.6 (C)
unnamed: D13.2 (A), SW4.2 (B)
unnamed: LED1.2 (A), R1.2
unnamed: LED2.2 (A), R2.2
unnamed: LED4.2 (A), R4.2

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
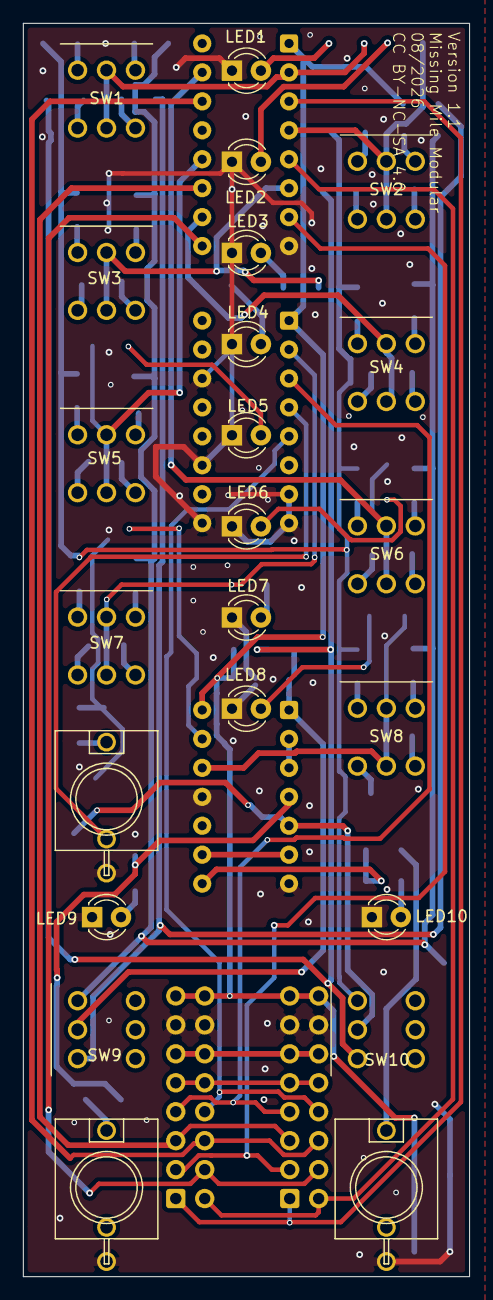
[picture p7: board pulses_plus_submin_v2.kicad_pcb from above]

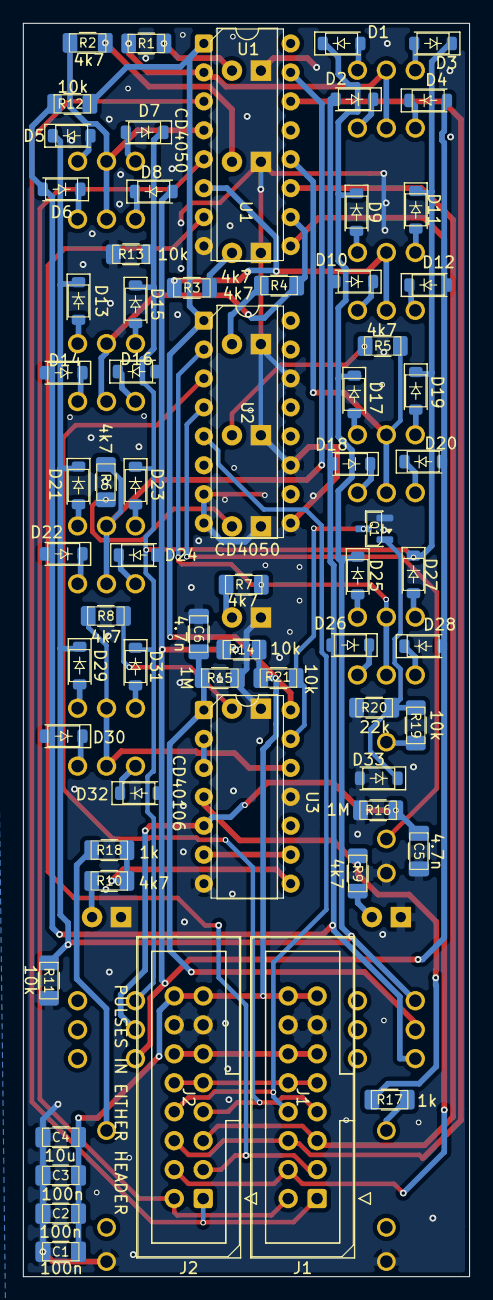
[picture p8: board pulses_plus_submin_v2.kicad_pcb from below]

Board: 2 copper layers, 39.2 x 110.0 mm, 89 parts (66 on the bottom side), 78 nets.

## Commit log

2026-08-09 Make pulses_plus_submin footprint and 3D refs portable
    The project had two references that only resolved on the machine it was
    authored on:
    - Thonkiconn_PJ301M.kicad_mod pointed its 3D model at
    ${KIPRJMOD}/SW-T2-4E-B-A2-MA2/3D/..., a directory that does not exist.
    The model is actually in 3d/, so repoint it there.
    - pulses_plus_submin_panel.kicad_pcb placed 27 footprints from a "Panel"
    library that is in neither the project fp-lib-table nor the tree; it
    resolved from a KiCad global table locally, so the panel would not open
    on a fresh clone. Vendor its three footprints (Hole_3.2mm, Hole_4.95mm,
    Hole_6mm -- each a single NPTH circular pad) into
    pulses_plus_submin.pretty and re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
    [pulses_plus_submin_panel.kicad_pcb]
2026-08-09 Add v2 panel in house style, and PANEL_STYLE v1.03
    New front panel for pulses_plus_submin, drawn to PANEL_STYLE. Every hole
    position, the Edge.Cuts outline and the copper are inherited verbatim from
    the v1 panel -- tools/build_panel_v2.py reads v1 and regenerates only the
    silkscreen, so the style guide's one non-negotiable rule (hole positions are
    inherited, never computed) holds by construction rather than by check. All
    27 holes verified identical to v1.
    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
    [pulses_plus_submin_panel_v2.kicad_pcb]
2026-08-09 Keep the NonCommercial clause: CC BY-NC-SA 4.0 on the panel back
    The v2 panel back read CC-BY-SA, which is a different licence from the
    CC BY-NC-SA 4.0 the v1 panel carries -- it would have permitted commercial
    builds of the module. Restores the NC clause and the version number.
    PANEL_STYLE goes to v1.04: the licence line now has to be the short form
    *with* its version, and says why the clause letters are not cosmetic.
    [pulses_plus_submin_panel_v2.kicad_pcb]
2026-08-09 v2 panel: standard mounting slots, copper decoration redrawn as silk
    Mounting is regenerated to the house rule instead of inherited. 8 HP is
    > 6 HP, so both columns and four 6.4 x 3.2 mm obround slots milled on
    Edge.Cuts, horizontal so the module can slide +/- 1.6 mm onto the rails.
    Centres sit 3.0 mm from the top and bottom edges; the 7.5 mm inset is the
    datum and the far column steps out 5 x 5.08 to 32.9, leaving a 7.26 mm
    margin on that side -- the grid is what the rail is drilled to, so that is
    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
    [pulses_plus_submin_panel_v2.kicad_pcb]
2026-08-09 new panel
    [pulses_plus_submin_panel-B_Cu.gbr, pulses_plus_submin_panel-B_Mask.gbr, pulses_plus_submin_panel-B_Paste.gbr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]
2026-08-09 README: pulses_plus_submin is the finished project, panel v4 is current
    Rewrites the README around the work in this fork rather than upstream's Rev 2
    board. Leads with pp.PNG, names Hardware/pulses_plus_submin as the built and
    tested hardware, and points at panel v4 as the current one. Adds a short
    account of how the module works -- the two-pole split that keeps an unselected
    bus from leaking, the OR/MUTE/AND mode stack, the normalled EXT jack -- plus
    key parts, how to regenerate the panel, the VCV Rack port, and how to read the
    panel's marks.
    Upstream's Rev 2 description and BOM are kept, under their own heading and
    credited to TomWhitwell/Turing-Pulse-Expander, since that board and its
    ge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
    [pulses_plus_submin_panel_v2.kicad_pcb, pulses_plus_submin_panel_v4.kicad_pcb]
2026-08-15 Split out as a standalone repository
    Pulses Plus is now its own project, extracted from the Turing-Pulse-Expander
    fork with its history intact. Nothing of Tom Whitwell's remains here; the
    upstream Rev 2 files and the superseded studies stay in the archive repo.
    Brought in alongside the split:
    - docs/pulses-plus-design.md, the design write-up, and the Taiway 200-MDP3
    datasheet, both previously in the shared Docs/ tree
    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
    [BOM_DigiKey.csv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]
2026-08-15 docs: repoint design-doc links that broke on the split
    The write-up references the generator scripts and the pulses_plus board files
    that stayed in the archive repository. Those links were relative to the old
    shared Docs/ tree and resolved to nothing here; they now point at the archive.
    Added a note up front so the distinction is not a trap: the circuit analysis
    describes the module you can build, but the generated-from-source build workflow
    it walks through belongs to the superseded full-size design. Only the panel is
    generated in this project.
2026-08-15 README: document the gate-on-A, quantizer-ping-on-B patch
    Mirrors the section added to the VCV port, rewritten for the board rather than
    copied: the two buses are two reads of one shift register, so their patterns
    cannot drift apart but can run at different densities, and that gap is where
    the module earns its keep.
    Bus A drives the envelope gates; bus B, on a sparser AND, pings a quantizer
    sampling the Turing Machine's CV, so the note holds across every gate A
    produces in between and changes only on beats the gate pattern already stresses.
    Records why pulse width is transparent end to end: the board is purely
    combinational and never reads the ribbon's CLOCK pin, because it does not need
    t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
2026-09-27 fixed edge case trig glitch
    **C5/C6 are the glitch filter** — 4.7 nF from each mode-switch common (`BUSA_SEL` / `BUSB_SEL`)
    to GND, sitting across R15/R16. They are not decoupling and not optional: without them the module
    passes a sub-µs stale-bit spike from the Turing Machine's expander bus through its Schmitt output
    buffers, which false-triggers edge-sensitive gate inputs (a Kassutronics ASR is the known case).
    **Do not substitute 1 n or 2.2 n** — 1 n was measured insufficient and 2.2 n computes marginal. See
    the design doc's *Stale-bit glitch* section.
    [BOM_DigiKey.csv, pulses_plus_submin_panel_v4.kicad_pcb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]
2026-09-27 Re-plot gerbers_v2 from the fixed board; register switch_fix in-project
    gerbers_v2 was plotted 2026-08-22, before C5/C6 and the thermal-relief
    fix, so the committed fab package no longer matched the board. Re-plotted
    all 12 files from pulses_plus_submin_v2.kicad_pcb using the board's own
    stored plot settings, with zones refilled.
    Verified against the board rather than against the old plot: 410 B.Cu and
    287 F.Cu flashes (123 SMD + 167 THT + 120 vias), 123 paste, 290 mask, and
    C5's pad coordinate now present. The old plot had 12 more flashes per
    copper layer because the pre-fix board carried 12 more vias.
    Add a project sym-lib-table for switch_fix. It was registered only in the
    user's global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
    [pulses_plus_submin_v2-B_Cu.gbr, pulses_plus_submin_v2-B_Mask.gbr, pulses_plus_submin_v2-B_Paste.gbr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]
